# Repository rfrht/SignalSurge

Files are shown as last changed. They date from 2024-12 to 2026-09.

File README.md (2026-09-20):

# SignalSurge
This is an open source (check licensing [here](https://github.com/rfrht/SignalSurge/blob/main/LICENSE)) Bandpass filter for VHF and UHF amateur radio bands, with a selectable LNA and a sequencer. Designed using Eagle CAD 9.

# Why?
I live in a highly RF-polluted metropolitan area. One of these days, only FFS I have added a FM bandstop filter and I found that, contrary to my belief, my reception was **way better**! That means:

1. The front-end radio filtering is less than great (even being an expensive FT-991A)
2. Strong out of amateur band signals (and there's **plenty** of them) will desensitize your radio
3. By filtering out unwanted signals, you give more **dynamic range** to your radio, improving your reception.
4. [See for yourself here](https://www.reddit.com/r/amateurradio/comments/1gxahma/noticeable_improvement_in_ft991a_2m_rx_when_using/).

That said, the objective of this project is to remove as much as possible signals outside 2m and 70 cm bands (like: FM broadcasts, air band, commercial VHF & UHF, and everything else inbetween), ensuring that the precious front-end gain on the radio's built-in amplifier focuses on amateur band signals as much as possible.

I could buy a [300 EUR filter](https://antennas-amplifiers.com/double-2x200w-bandpass-filter-144-148mhz-430-450mhz/), but... man, that's expensive. So why not spend €3,000 worth of my own man-hours and parts to build one?

# Features
* Two **selectable** amateur band (2m and 70 cm) [bandpass filter](https://github.com/rfrht/SignalSurge/blob/main/rf-performance.md) weeds out signals, ensuring that the transceiver front-end focus its gain figures on inband signals only. That can be automated by making use of the Band Data (`TUN/LIN` port, pins `4` or `5`). Requires menu config 141 (`TUNER SELECT`) to be set as `LAMP`.
* **High performance** and selectable [low noise 15 dB amplifier](https://github.com/rfrht/SignalSurge/blob/main/rf-performance.md#amplifier-performance) (Infineon BFP460) after the bandpass filter, adding some oomph to weak signals
* Nearly **-70 dB of rejection** against the FM broadcast band
* The amplifier is **shut down when the radio is transmitting** by powering off its 5V rail (by cutting the regulator "Enable" line) to prevent any artifacts/ringing and damage. 
* Specialty RF relay allowing 50W in VHF/UHF frequencies to flow to the antenna with **low loss**, while keeping **[unparalleled isolation](https://www.reddit.com/r/rfelectronics/comments/1h5mthn/comment/m0de8n7/) (north of 60 dB)** to the downstream components
* Relay **default state (NC) is to bypass** radio directly to antenna, allowing the board to be safely powered off
* [TX Inhibit](https://github.com/rfrht/FT-991A/blob/master/understanding-ft-991a-tx-inhibit.md) logic outputs +13.8V to the FT-991A's TUN/LIN port whenever the delicate BPF/LNA chain is active, **preventing accidental** 50W transmissions into the low-power solid-state switches and filter chain
* **Static bleeding and small [surge protection](https://www.digikey.com/en/products/detail/eaton-electronics-division/0603ESDA2-TR2/3681416)** when switched to BPF/AMP
* [Via-Stitched Grounded Coplanar Waveguides (GCPW)](https://resources.altium.com/p/pros-and-cons-of-different-high-frequency-transmission-line-types) ensures strictly controlled 50-ohm impedance and suppresses parasitic radiative modes. Real-world proof: the board effortlessly handles **50 Watts** (+47 dBm) of 70cm RF on an open bench **without radiating** into the room or causing the dreaded "speaker buzz" in nearby unshielded subwoofers.
* A **[detachable miniature](https://github.com/rfrht/SignalSurge/blob/main/others/miniature-filter-board.jpg)** VHF BPF filter that [fits perfectly](https://github.com/rfrht/SignalSurge/blob/main/others/miniature-filter.jpg) in [RTL-SDR](https://www.rtl-sdr.com/rtl-sdr-com-broadcast-fm-band-stop-filter-88-108-mhz-reject-now-for-sale/) [FM bandstop cases](https://github.com/rfrht/SignalSurge/blob/main/others/encased-miniature-filter.jpg). **NOTE:** This filter DOES NOT withstand TX power; it will **fry** the inductor! Do not transmit on it.

## Library
Eagle custom component library [here](https://github.com/rfrht/FT991A-PAT/blob/master/Schematic/aarf.lbr). Ensure to **also** fetch the latest library version (and update in your Eagle) when checking out new code.

Bill of Materials (CSV format, DigiKey format) [here](https://github.com/rfrht/SignalSurge/blob/main/others/SS.csv). Notice that there's a full RF Inductor and Capacitor kit specified in the BOM - and that is **costly**. If you have the suitable RF L/C components, fine! Otherwise (like me), buy a proper one.

# Schematic: 
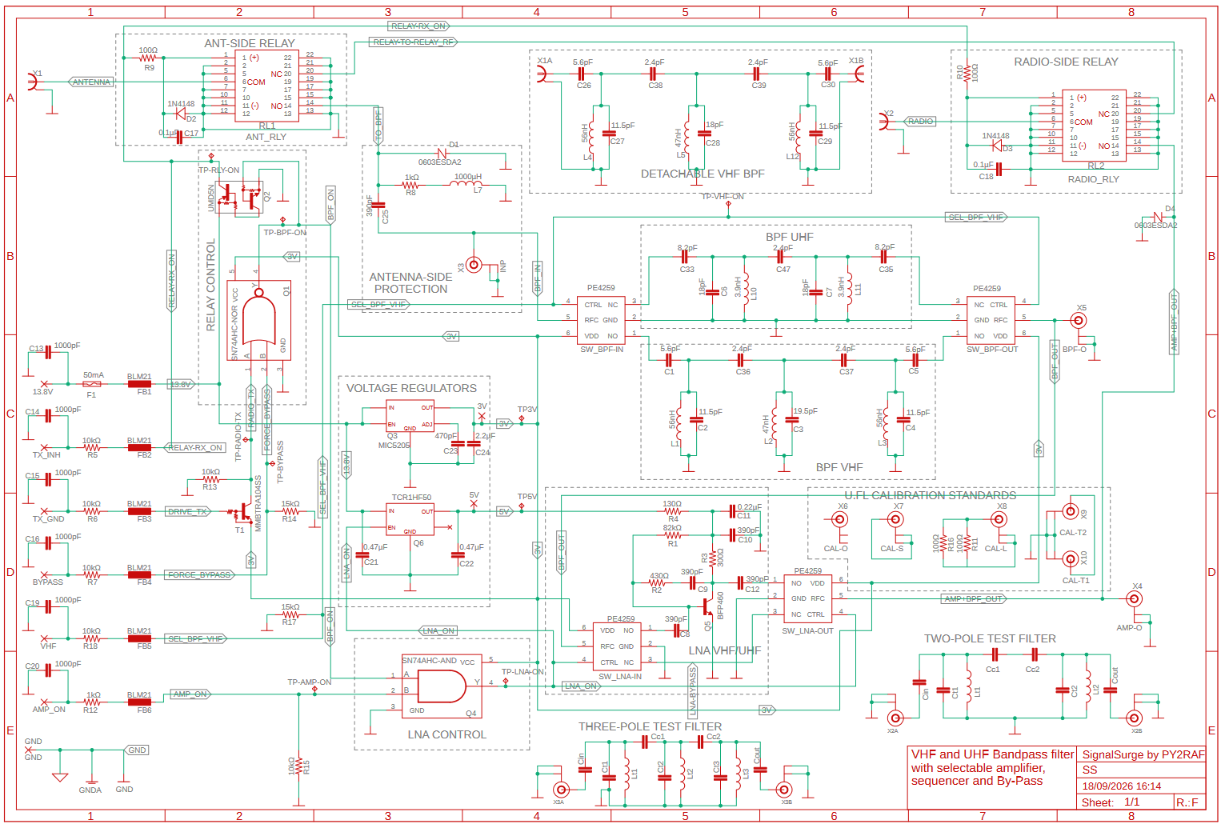
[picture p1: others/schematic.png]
Schematic SignalSurge


# Board layout
[Rev. E1 populated board](https://github.com/rfrht/SignalSurge/blob/main/others/ss-board-finished.jpg)

# BPF & Amplifier performance
Check the [test results](https://github.com/rfrht/SignalSurge/blob/main/rf-performance.md) page.

# Relay Logic
Check the [relay logic](https://github.com/rfrht/SignalSurge/blob/main/others/relay-logic.md) page.

# Test, troubleshooting steps & Specs
Yes - I have provided a [step by step testing and troubleshooting](https://github.com/rfrht/SignalSurge/blob/main/others/testing.md) guide!

# KNOWN ISSUES
**Ensure** to check the [Issues backlog](https://github.com/rfrht/SignalSurge/issues)

# JOURNEY
* Sep 18 - Updating the test figures. Successfully used the [TX INH](https://github.com/rfrht/FT-991A/blob/master/understanding-ft-991a-tx-inhibit.md) functionality at the radio. Released Rev. F.
* Sep 14 - Starting Rev. F. Changed "Bypass" and "VHF/UHF" selectors to input 5V in order to be able to use the [BCD decoders from FT-991 band data](https://hf5l.pl/en/1472-2/) at the TUN/LIN port. Added u.FL calibration pads.
* Sep 12 - Assembled board Rev. E1. Documented RF performance.
* Jun 06 - Improved UHF filter, making it narrower (50 to 30 MHz wide) and less lossy. Added another component in UHF schematic/board in order to allow for a fine tune capacitance of the coupling stage.
* May 28 - Fixed a gross error where a via shorted the VHF BPF final coupling stage. Removed ground pad on inductors at the detachable VHF BPF. Improved the radio signal trace at the first RF relay input. Updated component values for the 3-pole VHF filter (*in vivo* performed differently than the *in vitro*)
* May 04 - Replaced 3V regulator (was above its maximum rated) with a MIC5205. Removed a pulldown resistor in VHF line. Unified pulldowns on 10k and pulled lines limiters at 1k. Removed a pulldown between the NOR and AND logic ICs
* May 03 - Vibe-coded a new UHF filter with Gemini. Refactored the board, the filters, waveguides, soldermask, signal path
* May 01 - Starting Revision E. Vibe-coded a new VHF filter with Gemini
* Mar 19 - Removed two unneeded RF switches at the front-end: extra cost, complexity and insertion loss - unnecessarily, as the RF stage is handsomely isolated - and powered off during high power operations.
* Feb 28 - Found the need of a pulldown resistor in the VHF switch line. Refactored the CPW between the relays, hoping this tackle the high VSWR in 70 cm band.
* Feb 27 - Finished the board soldering, added the relays and SMA connectors. First back-to-back gain tests. First VSWR tests.
* Feb 22 - Pushing Rev. D
* Feb 20 - Finished BPF and LNA tests
* Feb/2026 - Got the Rev. C boards
* Dec 30 - Refactored the coplanar waveguides (CPW)
* Dec 29 - Changed layout of BPF section, separating inductors at 90° - Gemini said it's a good practice
* Dec 28 - Reviewed the board layout, added descriptions to signal lines, refactored the detachable VHF BPF, fixed a pernicious board cut failure to render (it was my fault)
* Dec 25 - [Used Gemini to design a VHF BPF](https://github.com/rfrht/SignalSurge/blob/main/others/gemini-prompt.md) - which yielded [pretty good results](https://github.com/rfrht/SignalSurge/blob/main/rf-performance.md), *tips hat to AI*
* Dec 25 - Starting Rev. C. 
* Aug 31 - Tested the VHF BPF and it was way out of line. Shelved the project for a while.
* Aug 31 - Added pulldown lines in comparators, routing change on the back of the board, unified logic ICs into SC70-5 footprint, updated BOM to add new pulldown resistors, better footprint for BFP460 and NCP553, fixed wrong 0.22µf part (it was 0.022µf) in BOM
* Jul 09 - Added a detachable board (taking advantage of the spare board real estate) that fits a RTL-SDR Bandpass filter. Minor signal and label revisions, routing, better labeling for signal I/O by adding expected voltages, improved semiotics. Tentatively final.
* May 18 - Fixed the Rev. A defects, check the [changelog here](https://github.com/rfrht/SignalSurge/commit/eed25a111f6a104a3589aa6e2ec3a4192e9d5c3d)
* Mar 17 - Tested relay logic (it is sound!), voltage regulators. And also fried the first board by shorting the 13.8V line on the 3V line **before** the fuse.
* Mar 16 - Tweaked the filter to bring the peak 2m BPF performance to the center of the band (146 MHz). Done in trial and error.
* Mar 11 - The boards arrived and assembled the Rev. A board - the BPF works! A bit out of frequency, but it works. More testing and component tweaking in the make.
* Feb 19 - All parts inventoried and accounted for. Placed the board order
* Feb 07 - Bought the needed parts!
* Jan/2025 - Reached the "minimally lovable project" stage.

# CHANGELOG
* Rev. F: Improved UHF BPF. Changed "Bypass" and "VHF/UHF" input selectors from 3V to 5V via resisitive divisors. Added u.FL calibration pads.
* Rev. E: Complete rewrite of VHF BPF to a proper 3-pole, improved UHF filter performance significantly, implemented a proper 50 ohm GCPW setup, re-added soldermask into the signal path, added a two-pole and three-pole test pad at the back of the board. Fixed u.FL connectors lacking connection to ground in one side. Added keep-out zones for inductors. Replaced the 3V regulator. Separated the top ground plane on north/south: The north (RF) section doesn't have any thermal relief in GND pads. The south (ancillary) section contains thermal relief GND pads.
* Rev. D: Changed 74XX pulldown lines to 100k, fixed UMD5N pin order, small tweak in UHF filter (caps changed to 20 pF). Added pulldown to VHF switch line. Rounded bypass CPW layout. Extra silkscreen. Removed exposed pads for shielding (might capacitive couple with the components). Removed unnecessary RF switches at the front-end.
* Rev. C: New VHF BPF topology, added a test UHF BPF on the back of the board, improved the LNA board layout, fixed capacitor pads (was too small)
* Rev. B: Added test points, changed connectors to SMA (big signal) and U.FL (small signal and test)
* Rev. A: Initial release

# ACKNOWLEDGEMENTS
I'd like to thank the following contributors:
* The fine [r/rfelectronics](https://www.reddit.com/r/rfelectronics/) community for helping me [square out a RX mute/isolation](https://www.reddit.com/r/rfelectronics/comments/1h0pffq/help_me_reuse_this_circuit/) (tip: it was right under my nose) issue and [how to select the large signal switch](https://www.reddit.com/r/rfelectronics/comments/1h5mthn/help_select_high_power_50w_uhf_switch/) and [a critical review of the bandpass filters](https://www.reddit.com/r/rfelectronics/comments/1hk1mgi/sanity_check_in_vhf_uhf_bpf_filters/)
* The [r/AskElectronics](https://www.reddit.com/r/AskElectronics/) community for [the sanity checking on using a PNP transistor to switch a ground signal](https://www.reddit.com/r/AskElectronics/comments/1hanp3u/will_this_switch_when_tx_gnd_is_grounded/).
* The mighty and fine [**Gordon Hudson** (AD5GG)](https://www.qrz.com/db/AD5GG) for: guiding me on component layouts, deciding for a proper impedance control, his primer on CPWs (coplanar waveguides) and assorted awesomeness.

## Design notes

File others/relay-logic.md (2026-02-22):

# BPF and Relay control
This is the documentation of the relay and RF switches state coordination.

## Truth table (NOR)
| RADIO_TX | FORCE_BYPASS | Logic Result | Behavior |
:---|---|---|---:
| 0 | 0 | 1 | VIA BPF |
| 0 | 1 | 0 | BYPASS |
| 1 | 0 | 0 | BYPASS |
| 1 | 1 | 0 | BYPASS |

## RX/Via BPF states:
| Circuit | Connected to  | Power |
:---------|---------------|--------:
| Relays  | NO | + |
| Isolation | NO | + |

## TX/Bypass states:
| Circuit | Connected to  | Power |
:---------|---------------|--------:
| Relays  | NC | - |
| Isolation | NC | - |

# LNA Control
## Truth Table (AND)
| BPF_ON | LNA_ON | Logic Result | Behavior |
:---|---|---|---:
| 0 | 0 | 0 | OFF |
| 0 | 1 | 0 | OFF |
| 1 | 0 | 0 | OFF |
| 1 | 1 | 1 | ON |

## LNA On
| Circuit | Connected to  | Power |
:---------|---------------|--------:
| V.REG.  | EN | + |
| LNA SW  | NO | + |

## LNA Off
| Circuit | Connected to  | Power |
:---------|---------------|--------:
| V.REG.  | EN | - |
| LNA SW  | NC | - |

The VHF/UHF selector is NORMALLY CONNECTED (NC) to the UHF BPF. By providing a 3V input to the VHF header, the BPF RF switches transition to NO (normally open) state and diverts the signal to the VHF chain.

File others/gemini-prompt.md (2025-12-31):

# BPF Gemini vibe designing
## Prompt
I want to create a radio frequency band pass filter centered at 146 MHz with bandwidth 4 MHz wide. What is the best topology for this filter, considering L, T or Pi networks? I don’t have any special need for delay groups. 

## Answer
For a filter centered at **146 MHz** with a narrow **4 MHz bandwidth** (approx. 2.7% fractional bandwidth), the standard "L," "T," or "Pi" networks used for broad low-pass or high-pass filtering are not suitable on their own.

The best topology for this application is the **Top-Coupled Capacitive Bandpass Filter** (often called a **Nodal** or **Tubular** filter).

While this topology visually resembles a chain of Pi-networks, it functions differently. It consists of parallel LC resonant tanks connected (coupled) by small series capacitors.

### Why this is the Best Topology
1. **Realizable Component Values:** If you tried to design this as a standard "Pi" bandpass (converting a Low Pass prototype directly), the series arm would require an inductor and capacitor in series that are impractical to realize at 146 MHz for such a narrow bandwidth. The top-coupled topology keeps all inductors as "shunt" elements (connected to ground), which is mechanically stable and easy to tune.
2. **High Q Capability:** A 4 MHz bandwidth at 146 MHz requires a Loaded Q of approximately 36.5. This topology allows you to use high-Q air-core inductors to minimize insertion loss.
3. **Tunability:** Since the inductors are grounded, you can easily use air-wound coils and stretch/compress them to tune the center frequency without desoldering components.
---

### Recommended Topology Structure
The filter is constructed as a cascade of **Resonant Tanks** coupled by **Series Capacitors**.

**Structure (3-Pole Example):**
`[Input Match] — [Tank 1] — [C12] — [Tank 2] — [C23] — [Tank 3] — [Output Match]`

* **Tanks (1, 2, 3):** Each "Tank" is an Inductor and Capacitor in parallel, connected between the signal line and ground.
* **Coupling Caps (C12, C23):** Small capacitors in series between the tops of the tanks. These control the bandwidth.
* **Input/Output Matching:** Since the impedance of the tanks is very high at resonance, you cannot connect a  cable directly to the top. You must "tap" down.
* *Option A (Inductive Tap):* Connect the input coax to a tap point roughly 1-2 turns up from the grounded end of the coil.
* *Option B (Capacitive Divider):* Split the resonant capacitor into two series capacitors. Connect the input between them.

### Design Guidelines (146 MHz)
Since you do not need flat group delay, a **Chebyshev** response (0.1 dB or 0.5 dB ripple) is recommended. It gives you sharper "skirts" (better rejection of signals at 140 MHz or 152 MHz) compared to a Butterworth filter.

#### 1. Component Selection
* **Inductors:**
* Use air-core coils. roughly **50 nH to 80 nH**.
* *Construction:* 4 to 6 turns of AWG 18-20 wire, roughly 6-8mm diameter.
* *Why:* High Q is essential. Do not use small SMD inductors; their Q is too low, and your filter will have high signal loss (Insertion Loss).

* **Resonant Capacitors:**
* Use High-Q RF capacitors (C0G/NP0 ceramic or silver mica).
* Value will likely be in the **15 pF to 30 pF** range.
* Include a trimmer capacitor (e.g., 2-10 pF) in parallel with each tank for fine-tuning.

* **Coupling Capacitors:**
* These will be very small, likely **1 pF to 4 pF**.
* Use high-precision (±0.1 pF) C0G capacitors.

#### 2. Layout & Shielding
* **Shielding is Critical:** Because the coils are air-core, they act like antennas. If Tank 1 "sees" Tank 3 magnetically, the filter will not work (the stop-band rejection will be ruined).
* **Solution:** Place each LC tank in its own small shielded compartment (using double-sided PCB material as walls), or orient the coils at 90-degree angles to each other to minimize magnetic coupling.

### Summary of Specifications

| Parameter | Value | Note |
| --- | --- | --- |
| **Center Freq** | 146 MHz | 2m Amateur Band |
| **Bandwidth** | 4 MHz |  |
| **Topology** | Top-Coupled Capacitive | Best for narrow band VHF |
| **Filter Shape** | Chebyshev | Best selectivity for component count |
| **Coupling** | Series Capacitors | Controls the 4 MHz width |
| **Matching** | Capacitive Divider | Matches 50$\Omega$ to High-Z tank |

**Would you like me to calculate the specific capacitor and inductor values for a 3-pole Chebyshev design (standard for this application)?**

## Prompt
Yes, please

## Answer
Here are the specific component values and design details for a **3-Pole Top-Coupled Bandpass Filter** centered at **146 MHz** with a **4 MHz bandwidth** (Chebyshev response, 0.1 dB ripple).

### 1. The Circuit Topology
The filter consists of three parallel LC tanks connected to ground, coupled together by small series capacitors at the top. The input and output are matched using capacitive dividers.

**Visual Representation:**

```text
Input (50Ω)
   |
  [Cm]         [Ck]         [Ck]         [Cm]
   |-----|------|-----|------|-----|------|----- Output (50Ω)
   |     |      |     |      |     |      |
 [C1]   [L1]  [C2]   [L2]  [C3]   [L3]   [RL]
   |     |      |     |      |     |      |
  GND   GND    GND   GND    GND   GND    GND

```

* **L1, L2, L3:** Air-core Inductors (shunted to ground).
* **C1, C2, C3:** Main resonant capacitors (shunted to ground).
* **Ck:** Coupling capacitors (series).
* **Cm:** Matching capacitors (series input/output).

---

### 2. Component Values

These values are calculated for a **60 nH** inductor base, which is a convenient size for 2-meter band filters (easy to wind and high Q).

| Component | Value | Practical Implementation |
| --- | --- | --- |
| **Inductors (L1, L2, L3)** | **60 nH** | **Air Core:** ~4 turns of AWG 18 wire, 6mm (0.25") diameter, spaced to length of ~8mm.<br>*(Adjust spacing to tune)*. |
| **Coupling Caps (Ck)** | **0.6 pF** | **"Gimmick" Capacitor:** Twist 2 insulated wires together for ~10mm. Trim length to tune bandwidth. Alternatively, use **0.5 pF** high-Q ceramic. |
| **Input/Output Match (Cm)** | **3.3 pF** | High-Q Ceramic (C0G/NP0). Use a standard **3.3 pF**. |
| **End Tank Caps (C1, C3)** | **16 pF** | Use a **10 pF fixed** + **10 pF trimmer** (Green). <br><br>*(Reduced value accounts for loading from Cm).* |
| **Middle Tank Cap (C2)** | **19 pF** | Use a **10 pF fixed** + **10 pF trimmer** (Green). |

### 3. Critical Construction Details

#### Why the values are "low"
You will notice the Coupling Capacitor is extremely small (**0.6 pF**). This is normal for a narrow bandwidth (4 MHz) at this frequency.

* If  is too **large**, the bandwidth will become **too wide** (e.g., 10-20 MHz).
* If  is too **small**, the bandwidth will be **too narrow** and insertion loss will rise.

#### The "Gimmick" Capacitor
Because 0.6 pF is hard to find with tight tolerance, builders usually create a "Gimmick" capacitor:

1. Take two 2-inch pieces of insulated wire (enamel wire or plastic coated hookup wire).
2. Twist them tightly together.
3. Solder one end of wire A to Tank 1, and one end of wire B to Tank 2. (Leave the other ends floating).
4. **Tuning:** Cut the twisted wire shorter with clippers. As you cut it shorter, capacitance decreases, and bandwidth narrows.

#### Tuning Procedure
1. **Center Frequency:** Adjust the **L coils** (stretch/compress) or the **Trimmer Capacitors** on C1, C2, and C3 to peak the signal at 146 MHz.
2. **Bandwidth:** If the filter is too narrow, increase  (twist more wire). If it is too wide, decrease  (cut the wire).

### 4. Expected Performance
* **Insertion Loss:** < 2.5 dB (Dependent on the Q of your hand-wound coils).
* **Return Loss:** > 15 dB (Good match to 50 Ohms).
* **Rejection:** Should provide excellent rejection of FM broadcast (98-108 MHz) and pager/commercial signals (150-160 MHz).

Would you like me to explain how to physically shield these coils to prevent magnetic coupling from ruining the filter response?

## Prompt
Yes, please

## Answer
For a filter with air-core coils at 146 MHz, shielding is not just a precaution—it is a requirement. Without it, the magnetic fields from Coil 1 will induce current directly into Coil 3 (skipping the middle stage), which destroys your stop-band rejection.

Here is how to physically construct the shielding.

### 1. The "Three-Chamber" Box Method (Recommended)
The standard professional approach is to build a "coffin" or box divided into three separate compartments. This isolates each LC tank completely.

* **Materials:** Double-sided copper-clad board (FR4 PCB material) or thin brass/tin sheet.
* **Construction:**
1. Cut a rectangular base plate (ground plane).
2. Solder vertical walls to create a box with 3 distinct square rooms (e.g., 20mm x 20mm each).
3. **The Divider Walls:** The walls separating the rooms act as the shields.

* **The Connection Hole:** Drill a small hole (approx 3mm) in the divider walls. The coupling capacitor (or the twisted wire "gimmick") passes through this hole to connect the top of Tank 1 to the top of Tank 2.
* *Note:* Keep the hole small. A large hole allows magnetic waves to leak through.

### 2. Orthogonal Coil Orientation (NOTE: Picked this method)
If you cannot build a full metal enclosure, you must orient the coils so their magnetic fields do not overlap. This is called "Orthogonal Placement."

* **Coil 1:** Mount horizontally (Left-to-Right axis).
* **Coil 2:** Mount vertically (Up-and-Down axis).
* **Coil 3:** Mount horizontally (Front-to-Back axis).

*Why this works:* The magnetic field lines of Coil 1 will hit Coil 2 at a 90-degree angle, inducing almost zero current.
*Limitation:* This is harder to do with 3 coils than with 2. The Chamber Method (#1) is superior for 3-pole filters.

### 3. The "Distance Rule" (Eddy Currents)
While shielding prevents coupling, placing a metal shield too close to a coil will kill its "Q" (efficiency). The magnetic field induces "eddy currents" in the shield wall, which turn your RF signal into heat.

* **Rule of Thumb:** Keep the shield walls at least **one coil diameter** away from the coil itself.
* *Example:* If your 60 nH coil is 6mm wide, the metal walls should be at least 6mm away from the copper wire on all sides.
* *Result:* Each compartment should be roughly 20mm x 20mm wide/tall.

### Summary Checklist for Construction
1. **Base:** Solid copper ground plane (un-etched PCB).
2. **Mounting:** Solder the bottom leg of the inductor and the bottom leg of the trimmer capacitor directly to the floor (ground plane) for minimal lead length.
3. **Isolation:** Solder vertical walls between Stage 1, 2, and 3.
4. **Coupling:** Pass the small coupling capacitor through a small hole in the wall.

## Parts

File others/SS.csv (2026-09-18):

Qty | Value | Parts | DigiKey
1 | 2.2µF | C24 | 490-GRM21BR71E225KE11KCT-ND
2 | 0.47µF | C21 C22 | 1276-6480-1-ND
1 | 0.22µF | C11 | 1276-6478-1-ND
2 | 0.1µF | C17 C18 | 1276-6840-1-ND
6 | 1000pF | C13 C14 C15 C16 C19 C20 | 732-8050-1-ND
1 | 470pF | C23 | 732-7837-1-ND
5 | 390pF | C8 C9 C10 C12 C25 | 399-C0805C391J4HACTUCT-ND
3 | 2.4pF | C34 C36 C37 | 311-3853-1-ND
1 | 1000µH | L7 | 587-2041-1-ND
6 | BLM21 | FB1 FB2 FB3 FB4 FB5 FB6 | 490-1041-1-ND
1 | 82kΩ | R1 | 118-CR1206-FX-8202ELFCT-ND
7 | 10kΩ | R5 R6 R7 R13 R15 R18 R19 | CR1206-FX-1002ELFCT-ND
2 | 15kΩ | R14 R17 | CR1206-FX-1502ELFCT-ND
2 | 1kΩ | R8 R12 | CR1206-FX-1001ELFCT-ND
1 | 430Ω | R2 | 118-CR1206-FX-4300ELFCT-ND
1 | 300Ω | R3 | CR1206-FX-3000ELFTR-ND
1 | 130Ω | R4 | 118-CR1206-FX-1300ELFCT-ND
2 | 100Ω | R9 R10 | CR1206-FX-1000ELFCT-ND
2 | 0603ESDA2 | D1 D4 | 283-0603ESDA2-TR2CT-ND
2 | 1N4148 | D2 D3 | 1801-1N4148WSR9GCT-ND
1 | MMBTRA104SS | T1 | 4878-MMBTRA104SSCT-ND
1 | 50mA | F1 | 283-3132-1-ND
2 | ANT_RLY | RL1 RL2 | PB2069CT-ND
2 | SMA-PCB | X1 X2 | 2072-RFPC-SMA28-F-ND
2 | SMA-EDGE | X1A X1B | 2057-RF2-145A-T-17-50-G-HDW-ND
3 | U.FL | X3 X4 X5 | A144746CT-ND
1 | SN74AHC-AND | Q4 | 296-8743-1-ND
1 | SN74AHC-NOR | Q1 | 296-11598-1-ND
1 | UMD5N | Q2 | UMD5NCT-ND
1 | MIC5205 | Q3 | 576-1258-1-ND
1 | BFP460 | Q5 | BFP460H6327XTSA1CT-ND
1 | TCR1HF50 | Q6 | TCR1HF50B-LM-CT
4 | PE4259 | Q7 Q8 Q9 Q10 | 1046-1011-1-ND
1 | Cap Kit | RF Capacitors | 712-1370-ND
1 | Ind Kit | RF Inductors | 712-1545-ND

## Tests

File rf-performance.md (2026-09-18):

# RF Performance

## VHF BPF
The VHF filter is a 3-Pole Top-Coupled Chebyshev Bandpass Filter. This is the first stab, simulated filter performance, modeled by LTSpice:

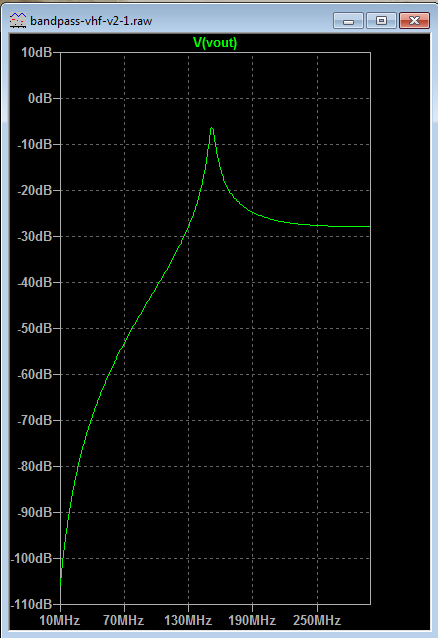
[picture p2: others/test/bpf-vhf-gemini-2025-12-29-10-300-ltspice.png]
Theoretical VHF filter


This is how the filter on 10 MHz - 300 MHZ VNA sweep of the VHF BPF - this was tapped right at the BPF stage, without any extra other insertion loss (switches, amps, etc). It provided a very decent isolation for the lower bands, FM broadcast and other general out-of-band signals.

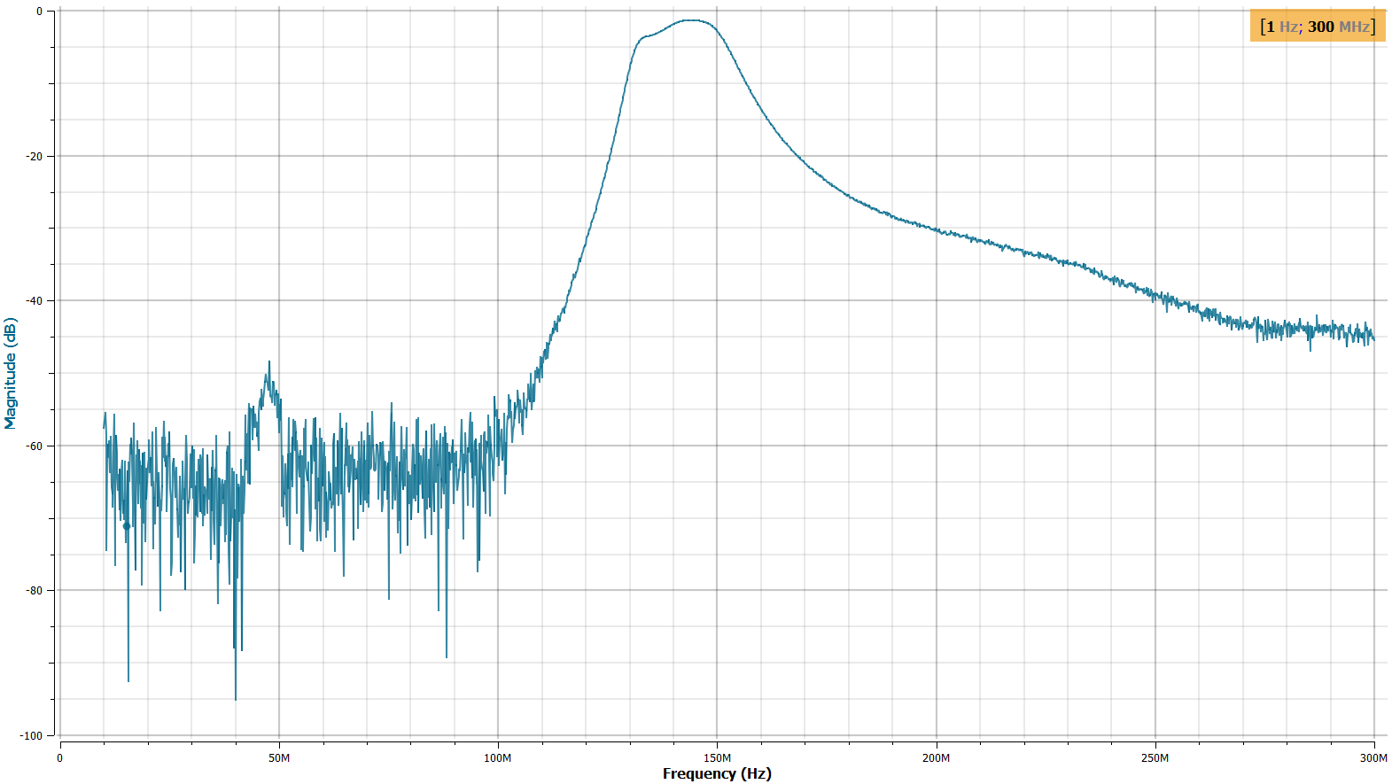
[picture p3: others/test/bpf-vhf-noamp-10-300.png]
Out of box VHF BPF


This is the VSWR and insertion loss sweep of the 2m amateur band - tested with a fully assembled board, SMA-to-SMA:

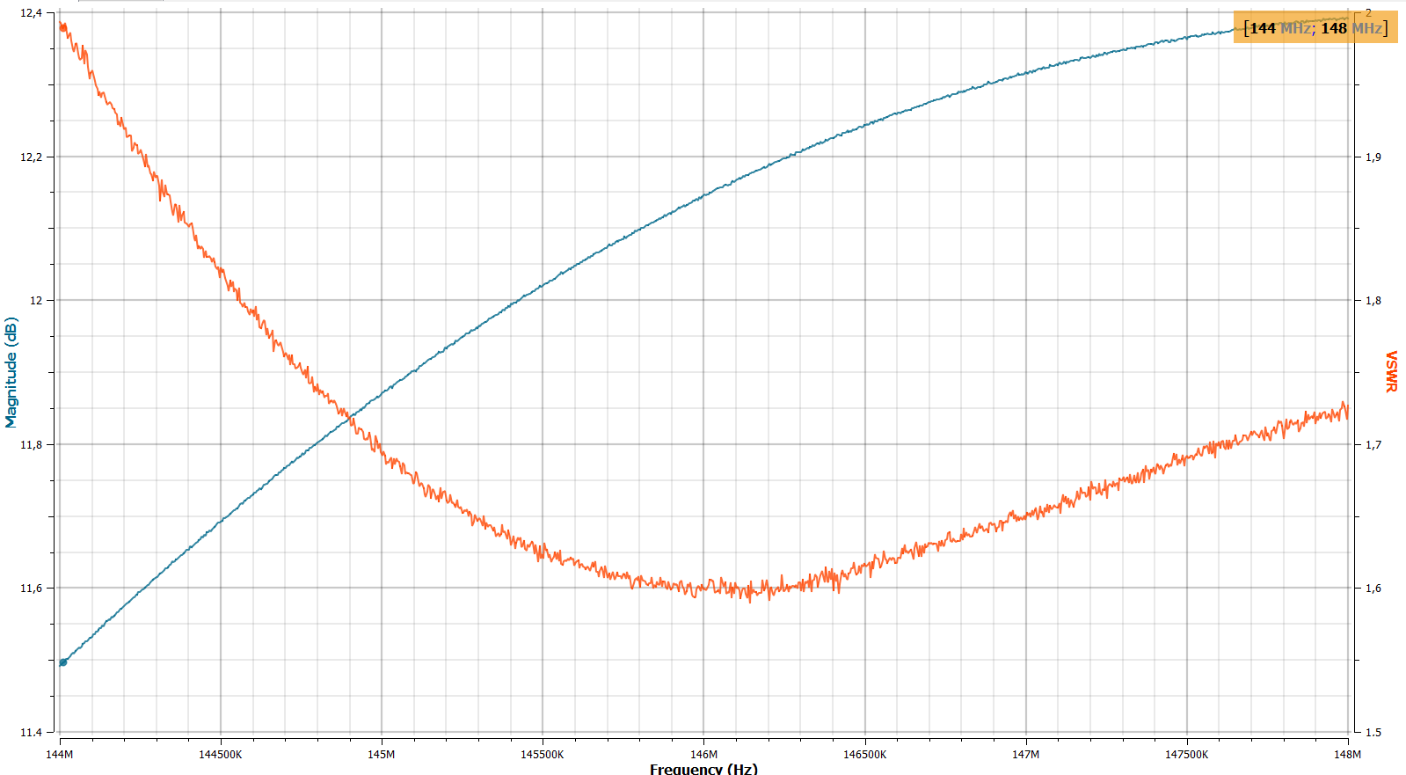
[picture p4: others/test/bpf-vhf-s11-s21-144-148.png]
2m VHF BPF SWR performance


And this is a insertion loss sweep in the broadcast band, which is my key pain - Almost the entire band under -60 dB:

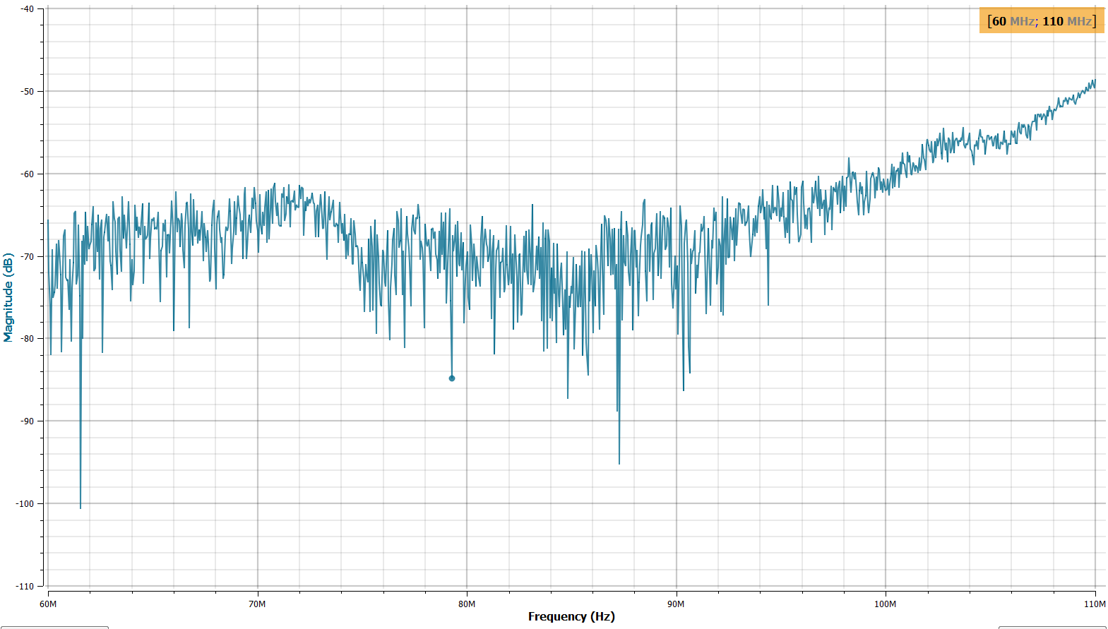
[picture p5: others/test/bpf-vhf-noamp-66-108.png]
FM Broadcast filter performance


## UHF BPF
The UHF filter is a 2-Pole Capacitively Coupled Parallel LC Resonator. Here is the theoretical projected filter performance:

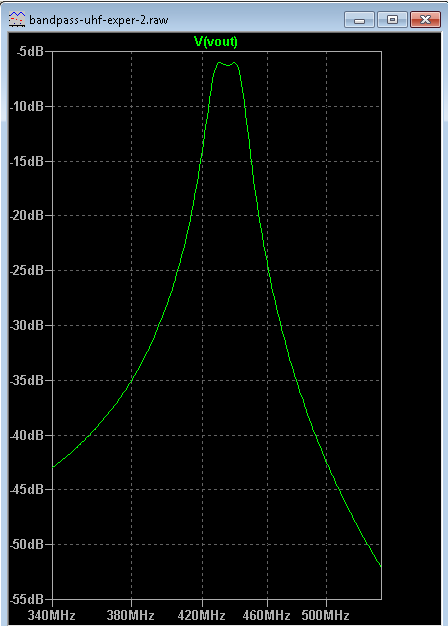
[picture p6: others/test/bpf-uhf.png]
Theoretical UHF BPF


And here is what the UHF filter delivered on a sweep from 10-600 MHz (testing it right at the BPF, without any extra insertion loss):

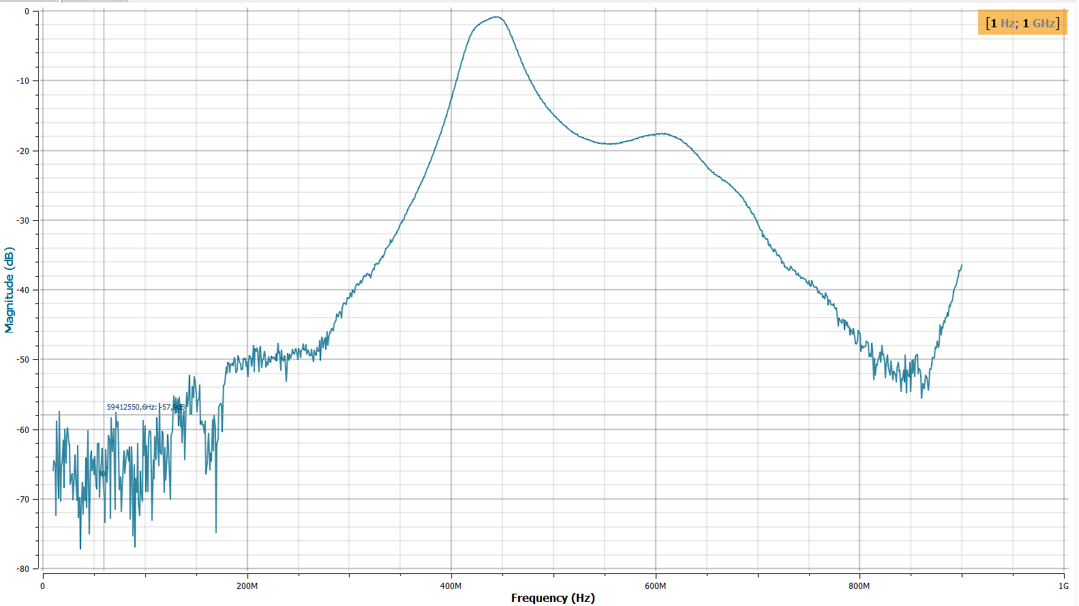
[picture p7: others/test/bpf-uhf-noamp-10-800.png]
UHF filter wide sweep


And this is how it is performing on 70 cm band, measuring insertion loss and VSWR in a fully assembled board, at the SMA connectors:

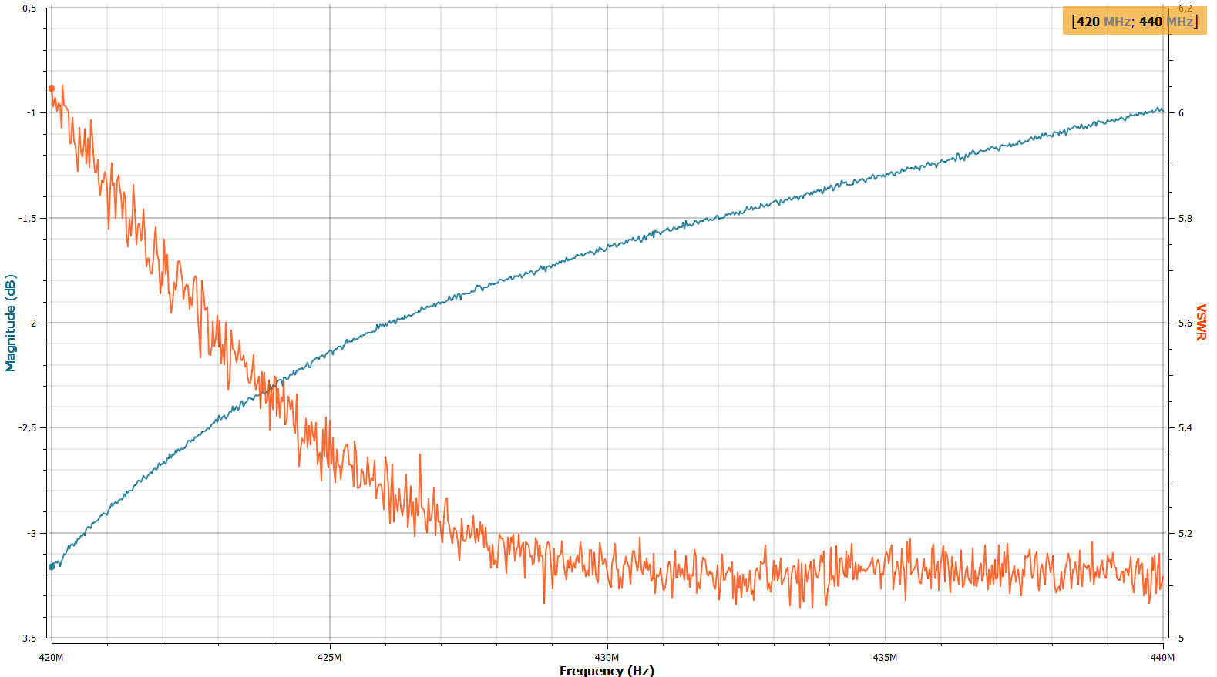
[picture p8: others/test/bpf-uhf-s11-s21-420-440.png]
70 cm band S11 and S21


## Amplifier performance
Here's the [BFP460](https://www.infineon.com/cms/en/product/rf/rf-transistor/low-noise-rf-transistors/bfp460/) gain figures, measuring solely the amplifier stage, without any extra insertion loss:

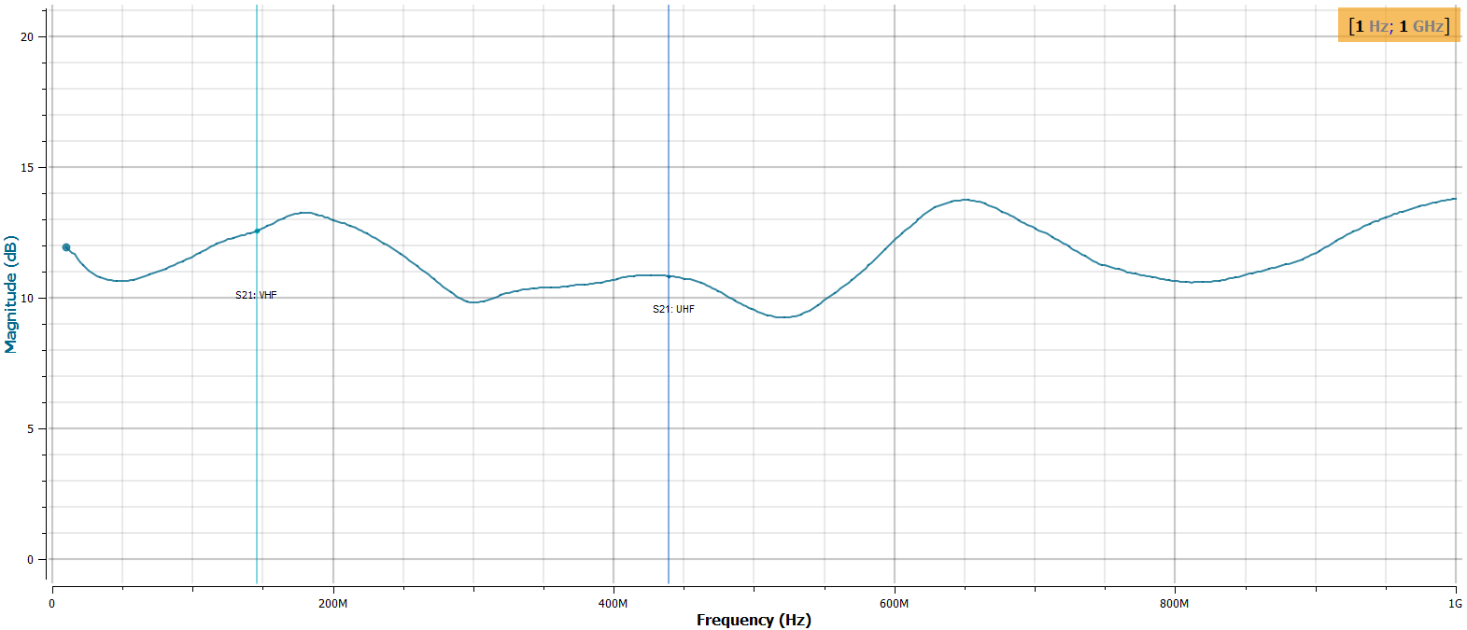
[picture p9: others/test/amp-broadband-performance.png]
Amplifier performance


The filter delivered approx. 10 dB of gain. 

Individual fully assembled board results, with signal travesrsing the BPF, connectors, switchetc etc, for VHF and UHF bands:

### VHF Gain
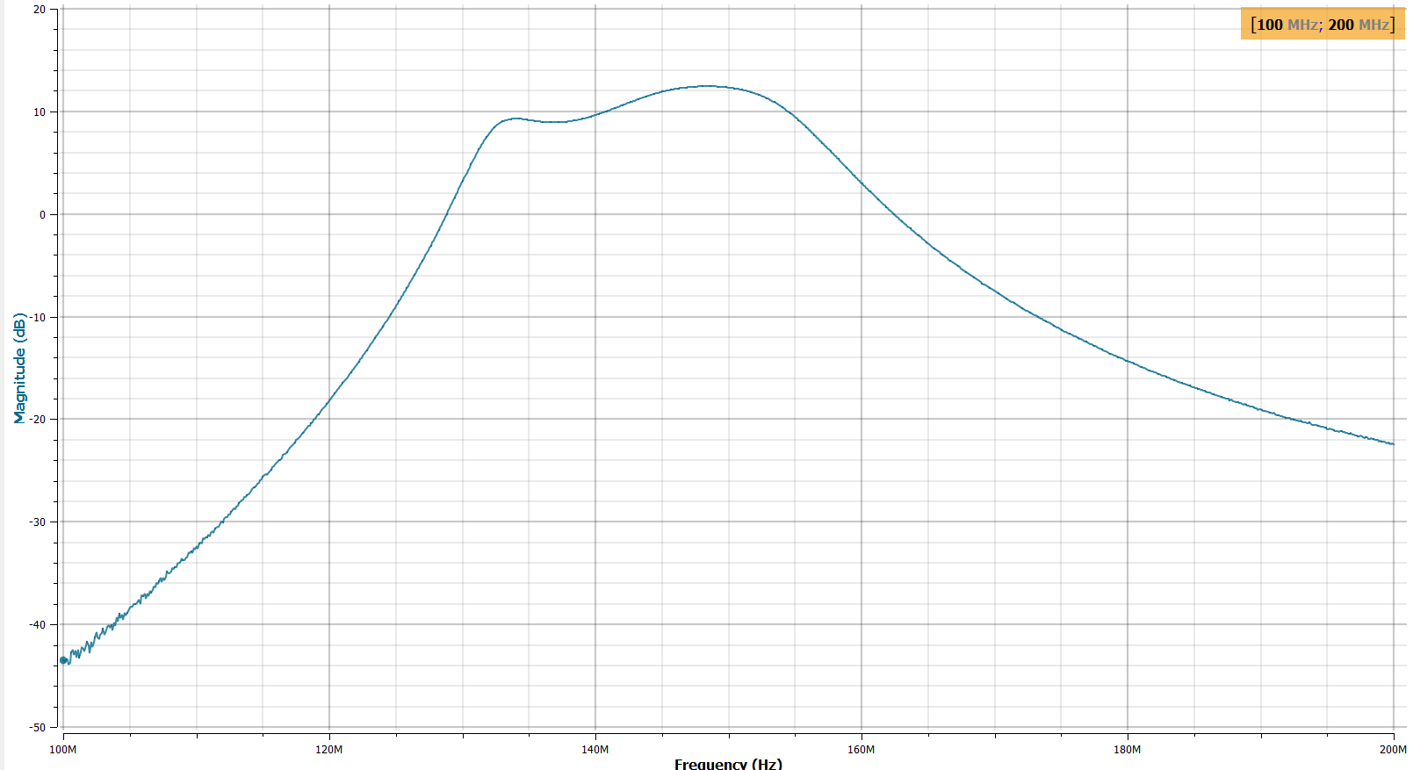
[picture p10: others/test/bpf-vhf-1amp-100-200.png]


### UHF Gain
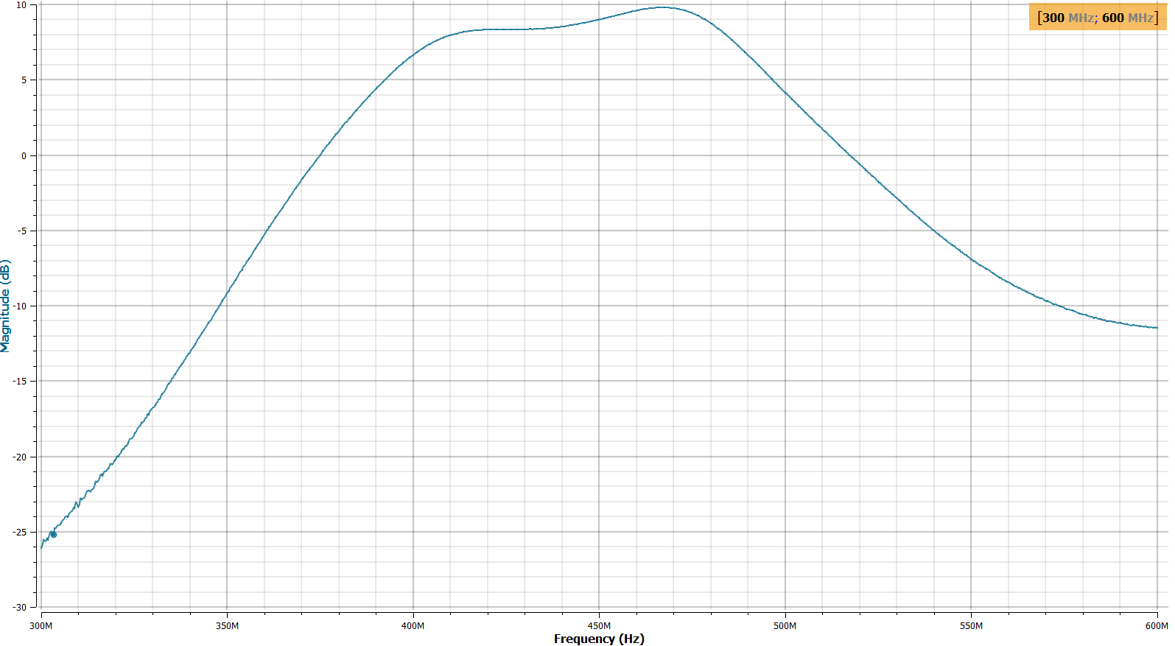
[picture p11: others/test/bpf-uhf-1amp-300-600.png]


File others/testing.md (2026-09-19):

# Device under Test
OOB VHF BPF

# Test sequence
Board picture - test sequence

* Start soldering the u.FL connectors `1` and `2`. Then the VHF/UHF BPF **discretes (caps & inductors) only**. Do not solder the RF switch just yet.

* Start testing with your VHF filter. Solder a bodge wire at the BPF RF switches footprints: They are `SW_BPF_IN` AND `SW_BPF_OUT` - requires good eyes and hands - to manually switch the VHF and UHF filters. Start bridging the u.FL with the **VHF BPF**.

* Now, measure the BPF performance. Inject signal from VNA Port 1 (Source) into the `INP` port (marked 1 in the image) and connect the VNA port 2 at the port `BPF-O`. Ensure that you have results similar to my [test results](https://github.com/rfrht/SignalSurge/blob/main/rf-performance.md).

* When all is fine, change your bodge wire to **switch it manually to UHF**. Redo the above test.

* When all is fine, remove the bodge wire from the `SW_BPF` RF switches. You might want to use solder wick to make your component footprint plain and remove excess solder. 

* Next up, solder the LOWER SECTION of the board: everything south of the BPF.

* Ensure that you have a solid 3V output at test point `TP3V`. Ensure that your fuse or any components (try with your fingers) aren't overheating.

* Feed 3V to the line `AMP_ON` header. Check the testpoint `TP_LNA_ON` have 3V and if your 5V regulator is throwing out a 5V output at the `TP5V` test point or the 5V terminal.

* Moving to the LNA. Solder a bodge wire at the `SW_LNA_IN` and `SW_LNA_OUT` pads, to bridge the U.FL lines `2` and `3` with the LNA stage.

* Inject signal from VNA Port 1 (Source) into the `BPF-O` connector, and measure the amplified output using VNA Port 2 (Receiver) at the `AMP-O` connector to correctly read S21 forward gain. Ensure that you are obtaining a good gain. If you mix the port order you will have a WRONG read! VNA port ordering is key here: Port 1 at `BPF-O`, Port 2 at `AMP-O`! Compare with my tests. And finally, ensure you soldered properly your BFP460. If you aren't getting any amplification, ensure that you didn't mix the VNA ports, have powered the LNA by powering the header `AMP_ON`.

* Remove the bodge wires. You may now solder the LNA RF switches.

* Redo the tests between the U.FL `BPF-O` and `AMP-O`, both ways: Amplifying and on bypass mode. Validate our outputs to establish a correctly working RF switch. NOTICE: they are FRAGILE! I damaged a number of them with a hot iron.

* Solder the BPF RF switches. Establish a working BPF switching between the u.FL connectors `INP` and `BPF-O`. Flip the switches by toggling the `VHF` line with 5V. Tip: You can tap 5V from the board header by turning on the amp by feeding 3V to the `AMP_ON` header.

* Solder the remaining parts at the UPPER SECTION of the board: First the SMD components, then the SMA port and finally the relays.

## Operational tests:

* When grounding `TX_GND`, all relays should be off. The same result is yielded when feeding 3V to the `BYPASS` port.

* When injecting 3V to `AMP_ON`, you turn on the amplifier. The presence of a `TX_GND` or `BYPASS` overrides and turns it off.

* The test point `TP5V` should be on only when `AMP_ON` has 3V at the header. Otherwise, it should be off.

* The line `TX_INH` sends 13.8V when the board is in RX mode (BPF/LNA engaged). When `TX_GND` or `BYPASS` are asserted, the board falls back to hardware bypass and the `TX_INH` line drops to 0V, safely allowing the radio to transmit.

* At the back of the board, there are the following tools: 2 pole filter, 3 pole filter and u.FL SOLT calibration pads.

If you have any further questions, get in touch or file an issue.

Yea, it'd be just easier if you bought that 300 EUR filter ;-)

## Power Consumption & Expected Current Draw
When troubleshooting the SignalSurge board, a standard multimeter placed in series with the main 13.8V power supply is your best diagnostic tool. The board operates at very low currents, making it easy to spot a blown component, a dead short, or a failed logic gate just by reading the milliamp (mA) draw.

The board is protected by a 50 mA PTC resettable fuse. If your board draws significantly more than the values below, immediately disconnect power and check for solder bridges/blobs/shorts or reversed diodes.

### Baseline Current Measurements
| Operational State | Expected Draw | Diagnostic Meaning |
| --- | --- | --- |
| **TX Mode / Manual Bypass** | **~0.5 mA** | **Quiescent State.** The Axicom HF3 relays are de-energized (hardware bypass) and the 5V regulator is either in shutdown or drawing minimal quiescent current. If this reads 0 mA, check your primary power connection. If it reads more than 1 mA, check the relay flyback diodes for leakage or shorts. |
| **RX Mode (BPF Only)** | **~18 mA** | **Relays Engaged.** The relay logic has successfully commanded the board to listen. The ~17.5 mA jump is the coil current required to physically hold the relays open, routing the RF signal through the PE4259 switch matrix and passive filters. |
| **RX Mode (BPF + LNA)** | **~24 mA** | **Full Active System.** The BFP460 amplifier is energized. The difference between this and the previous state is **~6 mA**. If the current jumps to > 30 mA here, the BFP460 is likely damaged or oscillating. |

### Being pedantic about power modes
* **Logic Override Test (`AMP_ON` + `TX_GND`):**
If `AMP_ON` is enabled and you trigger `TX_GND`, the current should instantly drop from **24 mA back to around 1 mA**.
* **VHF vs. UHF Logic Test:**
Toggling the FT-991A from 2-meters to 70cm (triggering BCD Pin 4) DOES NOT change the current draw. Switching between the PE4259 routing paths should result in a statistically zero difference in current (microamps). If you see a noticeable mA jump when switching bands, one of the RF switches is likely shorted to ground.
* **`TX_INH` Load Test:**
When connecting `TX_INH` to the radio, the `TX_INH` line sends +13.8V back to the radio and the total board current rises by around 1 mA when physically connected to the transceiver.

# Specifications
## Signal routing
### RX
* The signal enters the SMA Antenna connector
* Enters the first Axicom HF3 relay
* Finds a Eaton TVS PolySurge surge protector
* Static draining via a 1 kohm and 1000 µH inductor
* Encounters a 390 pF decoupling capacitor
* `INP` u.FL test port
* First RF switch, selects between VHF or UHF bandpass filter
* Enters the selected BPF
* Second RF switch, the exit section from the bandpass filter
* `BPF-O` test port
* Third RF switch, selects between the LNA section or bypass it, no amplification
* Fourth RF switch, LNA/bypass exit
* `AMP-O` test port
* Finds a Eaton TVS PolySurge surge protector
* Second Axicom HF3 relay
* Exit to radio port via SMA connector

All relays are protected by a 100 ohm current limiter resistor, a 1N4148 flywheel diode and a 0.1µF capacitor.

### TX
* The amplifier is de-energized by pulling off the `ENABLE` line from the 5V voltage regulator when detecting the `TX_GND` signal
* The signal enters the board via the SMA Radio connector
* Enters the first Axicom HF3 relay
* The signal is moved to the second Axicom HF3 relay
* Exit to the antenna

## Radio Frequency Performance
### General Specifications
* **System Impedance:** 50 ohms
* **RF Switching Matrix:** Four cascaded pSemi PE4259 ultra-high isolation RF switches
* **Switch Matrix Insertion Loss (Bypass Mode):** ~1.5 dB at 144 MHz; ~3.0 dB to 4.1 dB at 440 MHz
* **System Architecture:** Independent electronic selection for VHF/UHF filter paths and LNA amplification, backed by a hardware-level transmit ground (`TX_GND`) fail-safe bypass

### VHF Bandpass Filter (2-Meter Band)
* **Topology:** 3-pole capacitively-coupled LC bandpass filter built with Johanson High-Q wirewound inductors and C0G low-ESR capacitors
* **Center Frequency Target:** 144.0 MHz – 148.0 MHz
* **Passband Insertion Loss:** 1.33 dB at 144.9 MHz
* **Passband Return Loss (S11):** Better than -10 dB, dipping to -23.7 dB (VSWR 1.13:1)
* **FM Broadcast Rejection (88–108 MHz):** -59 dB to -69.4 dB attenuation. This extreme low-side skirt prevents local 100 kW commercial FM transmitters from driving the active stage into non-linear intermodulation.
* **Aviation Band Rejection (110–130 MHz):** >45 dB of attenuation below 110 MHz

### UHF Bandpass Filter (70-Centimeter Band)
* **Topology:** 2-pole capacitively-coupled LC bandpass filter using Johanson High-Q components
* **Center Frequency Target:** 439.0 MHz (Optimized for Brazilian repeater outputs)
* **Passband Insertion Loss:** 1.05 dB to 1.12 dB at 439.0 MHz
* **Absolute Peak Insertion Loss:** 0.90 dB near 444.0 MHz
* **Impedance Matching:** Utilizes 8.2 pF input/output series matching capacitors to overcome the inherently low characteristic impedance of the 3.9 nH core tanks. This ensures that the ~1 dB of measured loss is strictly reflective mismatch rather than absorptive thermal dissipation, preserving signal integrity before amplification.

### Low Noise Amplifier (LNA) Stage
* **Active Component:** Infineon BFP460 wideband NPN RF transistor
* **Topology:** Wideband shunt-shunt feedback LNA with a passive resistor-divider bias network
* **DC Operating Point:** Conservatively biased at approximately 4 mA Collector Current (Ic) and 3.2V Collector-Emitter Voltage (Vce). This low-power state ensures absolute unconditional stability and preserves the transistor's low intrinsic noise figure (~1.1 dB).
* **Raw Active Gain:** +15 dB to +16 dB broadband gain across both VHF and UHF frequencies
* **Net System Gain (Filter + Matrix + LNA):** +11.97 dB at 144 MHz and +11.90 dB at 439 MHz. The amplifier completely overcomes the combined insertion losses of the passive filters and the 4-stage switch matrix.

## System Protections & Operational Logic

### Hardware & Transmit Protections
SignalSurge is designed to sit directly in the primary RF path of a 50W transceiver. To prevent accidental destruction of the highly sensitive receive components, the board employs multiple layers of hardware-level protection:
* **Fail-Safe RX Architecture:** The primary signal path is controlled by robust Axicom HF3 mechanical relays. Their unpowered, default state is a direct hardware bypass (Antenna -> Radio), ensuring the transceiver can safely transmit even if the board loses power.
* **Transmit Inhibit (`TX_INH`):** When the active RX chain (filters and LNA) is engaged, the board outputs a continuous +13.8V signal to the Yaesu FT-991A's TUN/LIN port. This physically inhibits the radio from transmitting, ensuring 50W of RF is never dumped into the pSemi PE4259 switches (which have a maximum rating of 2W / +33 dBm).
* **Absolute TX Override (`TX_GND`):** Grounding the `TX_GND` line forces the Axicom relays into bypass mode and actively pulls the `ENABLE` line on the 5V regulator low, instantly de-energizing the BFP460 amplifier. This signal trumps all other board logic.
* **ESD & Static Drainage:** Both the antenna and radio ports are guarded by Eaton TVS PolySurge protectors. The antenna port also features a 1 kR resistor and 1000 µH inductor network to bleed off atmospheric static charge before it can reach the solid-state switching matrix.
* **Relay Coil Suppression:** Every mechanical relay coil is isolated with a 100 R current limiting resistor, a parallel 1N4148 flyback diode, and a 0.1 µF decoupling capacitor to suppress inductive voltage spikes during switching.
* **Overcurrent Defense:** The main power rail is protected by a PTC resettable fuse to guard against dead shorts.

### Automated Band Logic & Routing
The board utilizes a hybrid switching approach to maximize both power handling and receive isolation.
* **Solid-State RX Routing:** While the Axicom relays handle the high-power TX bypass, the internal receive path is entirely governed by four pSemi PE4259 RF switches. These provide ultra-high isolation between the VHF filter, UHF filter, and LNA stages without the mechanical wear or contact bounce of traditional relays.
* **Yaesu BCD Integration:** SignalSurge achieves "set-and-forget" automation by reading the BCD encoder outputs from the FT-991A's TUN/LIN port. By monitoring Pin 4 (Band Data B), the board automatically flips the internal solid-state switches between the 144 MHz and 430 MHz bandpass filters exactly as you change bands on the radio dial.
* **Manual Overrides:** Independent +3V header lines for `AMP_ON` and `BYPASS` allow the operator to manually force the LNA on or drop the entire board into hardware bypass.

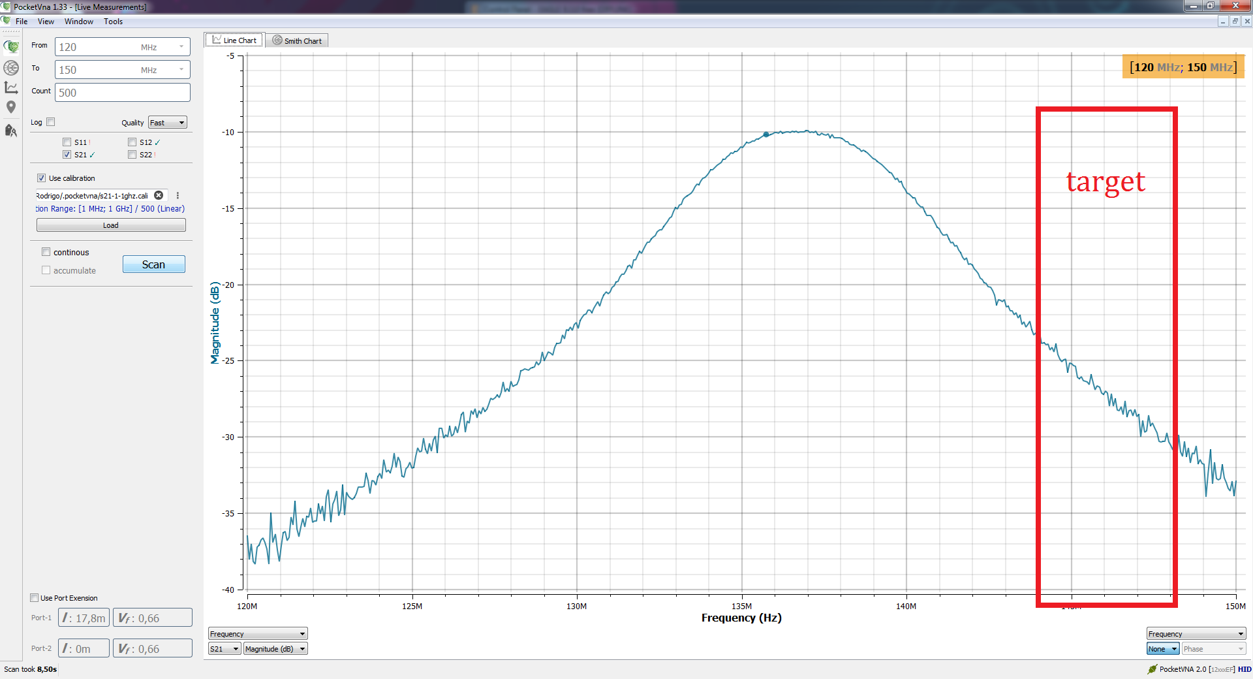
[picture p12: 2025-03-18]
others/test/bpf-vhf-oob-2025-03-13-120-150.png

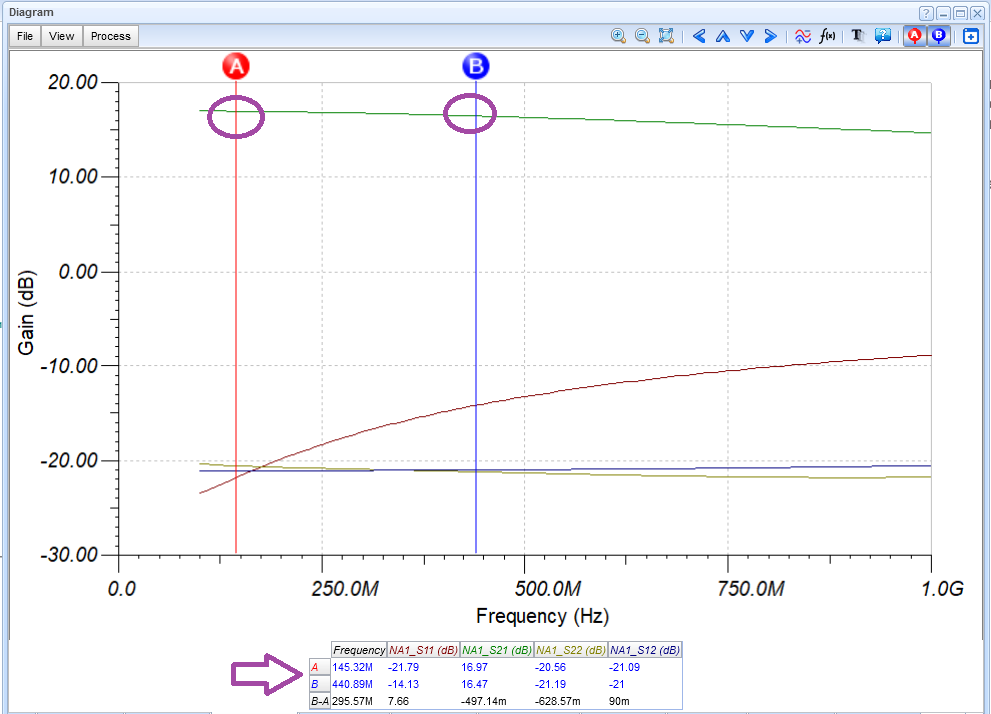
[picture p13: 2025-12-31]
others/test/bfp460-gain-fig.png

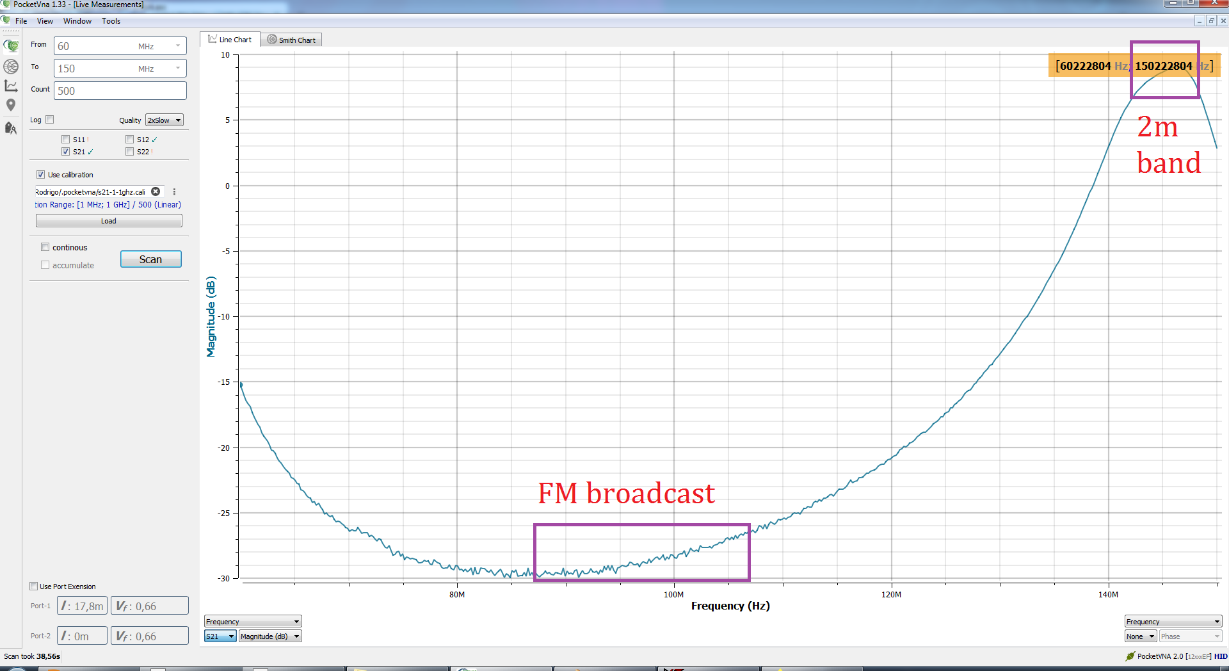
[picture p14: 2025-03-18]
others/test/bpf-vhf-amplified-2025-03-17-60-150.png

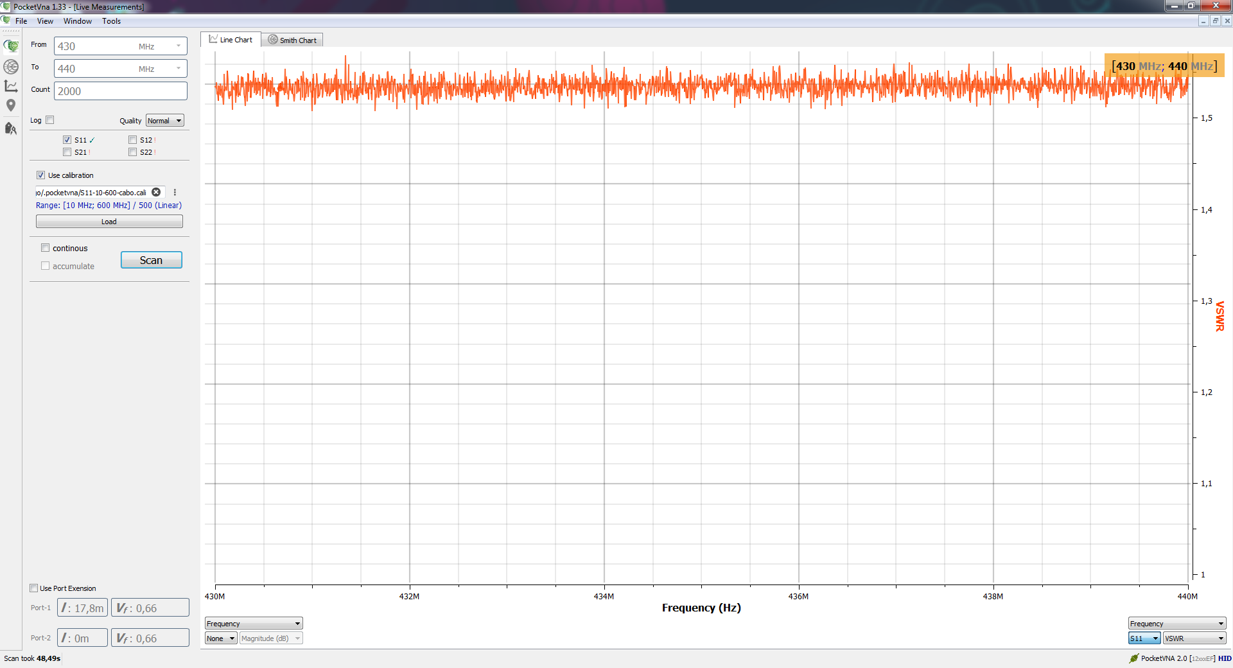
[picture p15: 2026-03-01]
others/test/vswr-430-440.png

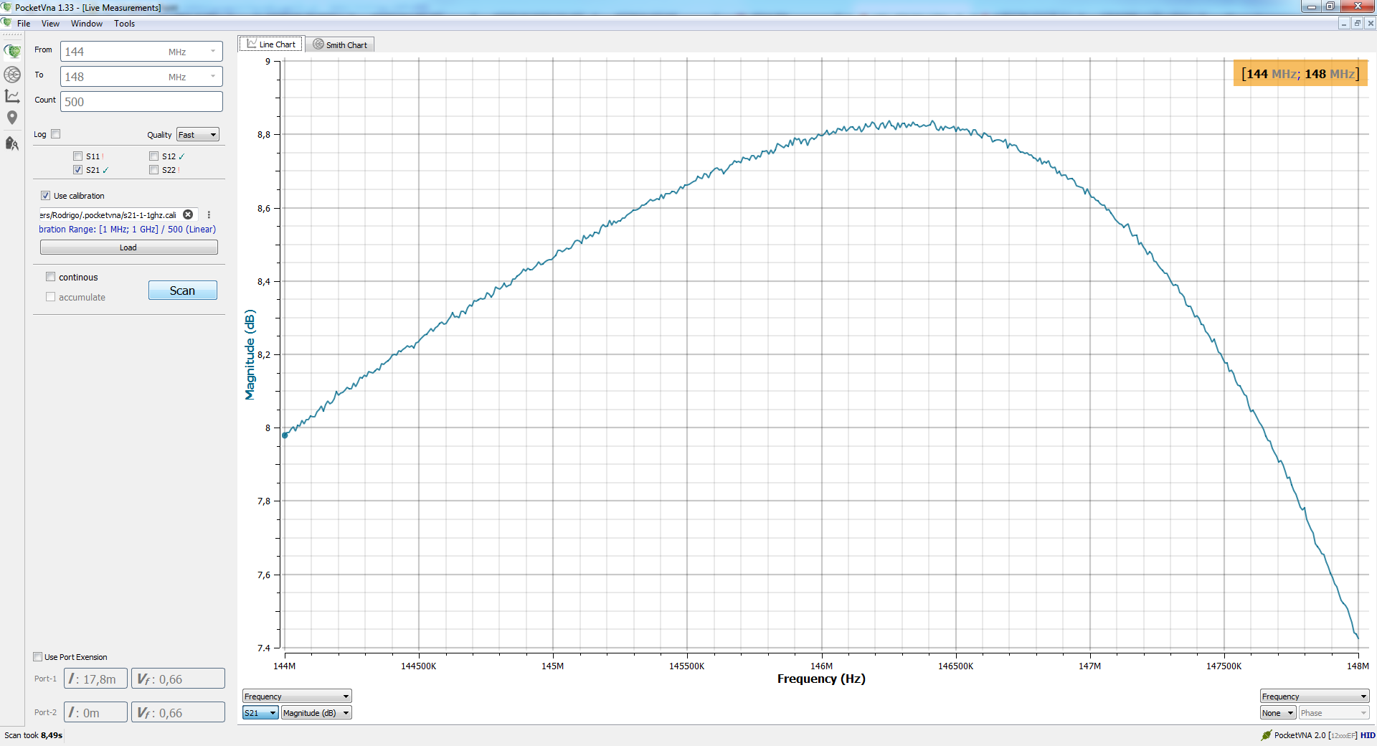
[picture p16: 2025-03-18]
others/test/bpf-vhf-tuned-2025-03-16-144-148.png

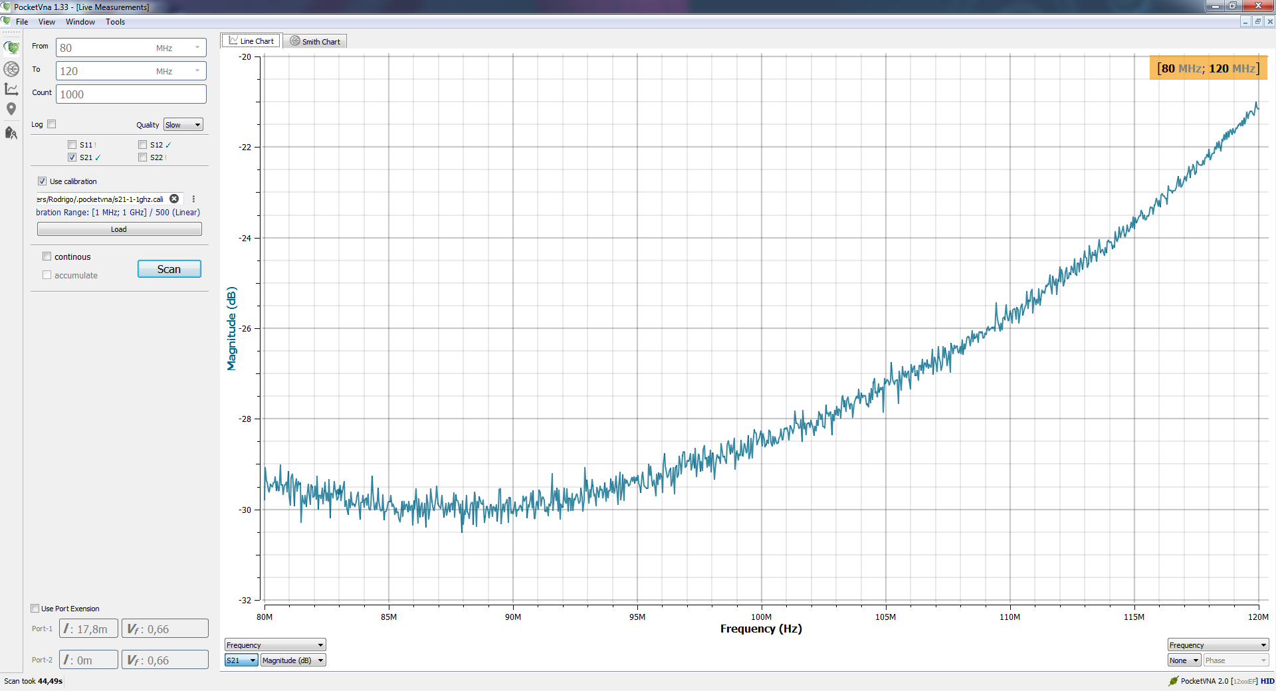
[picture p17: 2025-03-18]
others/test/bpf-vhf-tuned-2025-03-16-80-120.png

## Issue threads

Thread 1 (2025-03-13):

Add u.FL footprint in key areas

rfrht, 2025-03-13:
Add u.FL footprint at:

* Right after relays
* BPF out

rfrht, 2025-05-19:
Done!
1. One at the circuit input
2. one after the BPF
3. one after the amp/circuit output.

Closed 2025-05-19.

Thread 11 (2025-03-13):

Pad VHF BPF CPW

rfrht, 2025-03-13:
The right-side CPW on VHF BPF is too close to the solder pads; some soldered components can short to the ground. Improve spacing.

Closed 2025-05-19.

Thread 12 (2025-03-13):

Change SN74-OR solder pad to the one with longer pads

rfrht, 2025-03-13:
SN74-OR logical gate solder pads are too damn short. Use the same pad as the SN74-AND.

Closed 2025-05-19.

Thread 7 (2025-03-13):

Test relay logic

rfrht, 2025-03-13:
Ensure that the relay logic is sound.

rfrht, 2025-03-18:
Checked the gate configuration and it is sound.

There might be a need for a pulldown resistor on the AMP ON line.

Closed 2025-03-18.

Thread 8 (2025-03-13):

Test electric supply

rfrht, 2025-03-13:
Ensure that the power distribution is sound and correct.

Closed 2025-05-19.

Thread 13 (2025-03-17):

BOM issues

rfrht, 2025-03-17:
The following parts are missing in BOM:

* [BLM21](https://www.digikey.com/en/products/detail/murata-electronics/BLM21AG102SN1D/468922)
* 220 nF (C11)

rfrht, 2025-03-17:
C22 (0.1 µF) footprint is 0805, BOM specifies 1206. Change BOM part to 0805.

rfrht, 2025-03-17:
The following parts are specified but not used:

* [LB3218T102K](https://www.digikey.com/en/products/detail/taiyo-yuden/LB3218T102K/1788933)
* [MLF2012D82NMT000](https://www.digikey.com/en/products/detail/tdk-corporation/MLF2012D82NMT000/504203)

Remove them

Closed 2025-05-19.

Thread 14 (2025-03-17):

Wrong 5V voltage regulator specified

rfrht, 2025-03-17:
The specified L78L05 **does not provide** the Enable functionality - and to add insult to the injury, the footprint is also wrong.

rfrht, 2025-05-19:
Replaced with [Toshiba TCR1HF50B](https://www.digikey.com/en/products/detail/toshiba-semiconductor-and-storage/TCR1HF50B-LM-CT/18875465)

Closed 2025-05-19.

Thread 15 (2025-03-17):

Improve footprint for NCP553

rfrht, 2025-03-17:
NCP553 footprint isn't helpful at all; improve it

rfrht, 2025-05-18:
* Fattened the footprint significantly (to be seen how does that goes)
* Added the pin 1 marker to the middle of pin 1/2.

Closed 2025-05-19.

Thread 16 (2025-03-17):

Improve footprint for UMD5N

rfrht, 2025-03-17:
* Put the pin 1 dot in a more legible place (it's a stripe)
* Increase the pad size

rfrht, 2025-05-18:
* Moved dot to a more external place
* Increased pad size
* Added a stripe in the pin 1/6 side

Closed 2025-05-19.

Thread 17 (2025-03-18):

Double-check UMD5N connections

rfrht, 2025-03-18:
After soldering the UMD5N the PTC fuse triggered and the board went in undervoltage.

Double-check:

- Component footprint
- Component schematic
- Implementation on the board

rfrht, 2025-05-18:
The component was set up wrongly in the original schematic - flipped 180 degree. Shit all around.
Fixed.

Closed 2025-05-19.

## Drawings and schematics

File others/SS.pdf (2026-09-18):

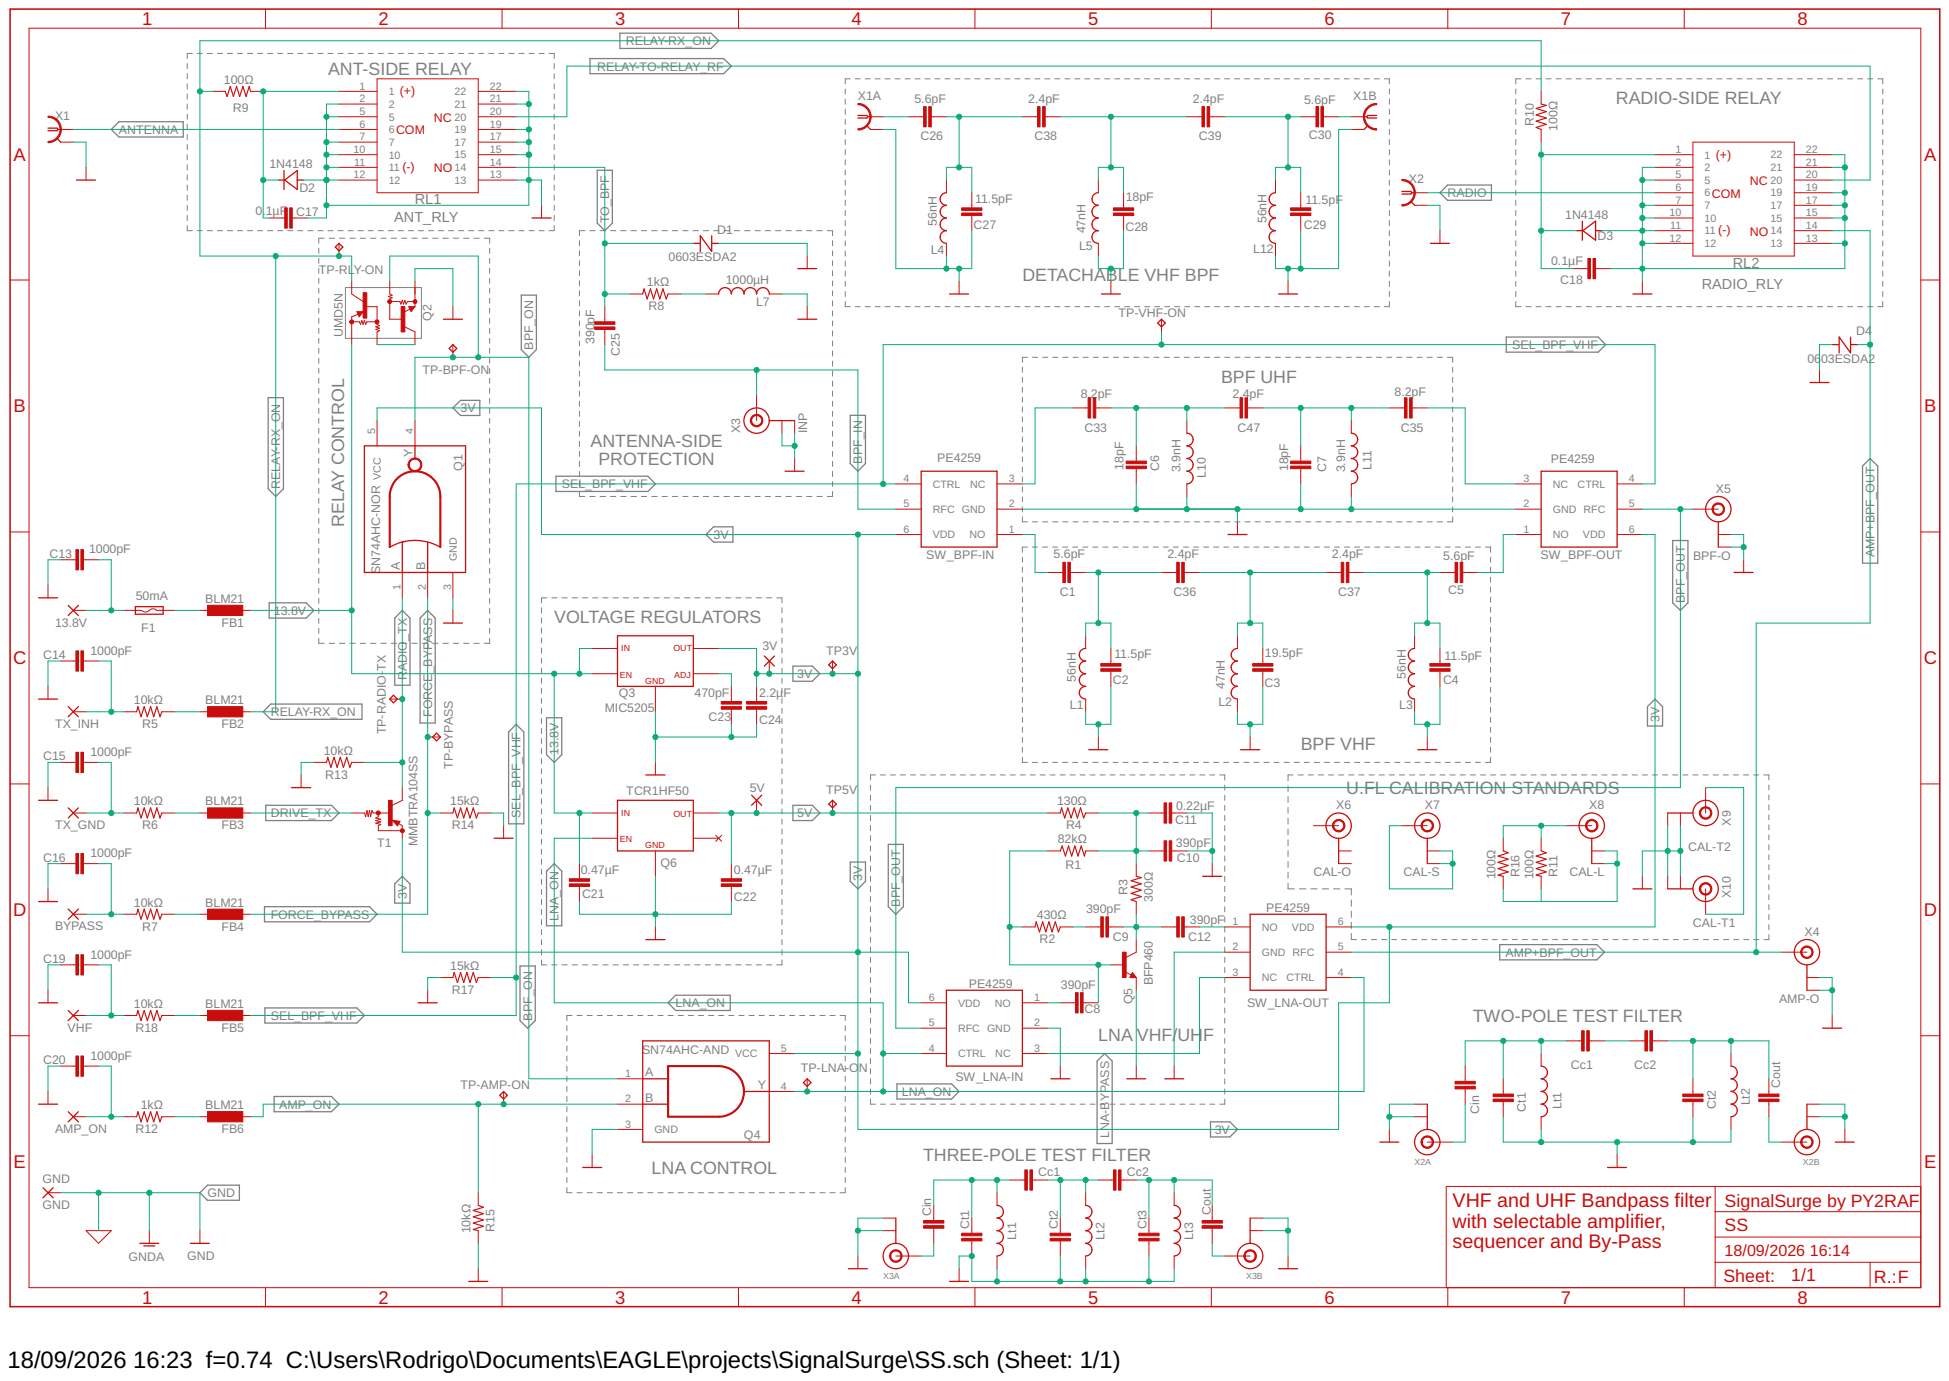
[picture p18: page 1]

5 | 20
6 7 | 19

6 | 19
7 | 17
10 | 15
11 12 | 14

TWO-POLE TEST FILTER

THREE-POLE TEST FILTER

VHF and UHF Bandpass filter with selectable amplifier, sequencer and By-Pass

18/09/2026 16:23 f=0.74 C:\Users\Rodrigo\Documents\EAGLE\projects\SignalSurge\SS.sch (Sheet: 1/1)

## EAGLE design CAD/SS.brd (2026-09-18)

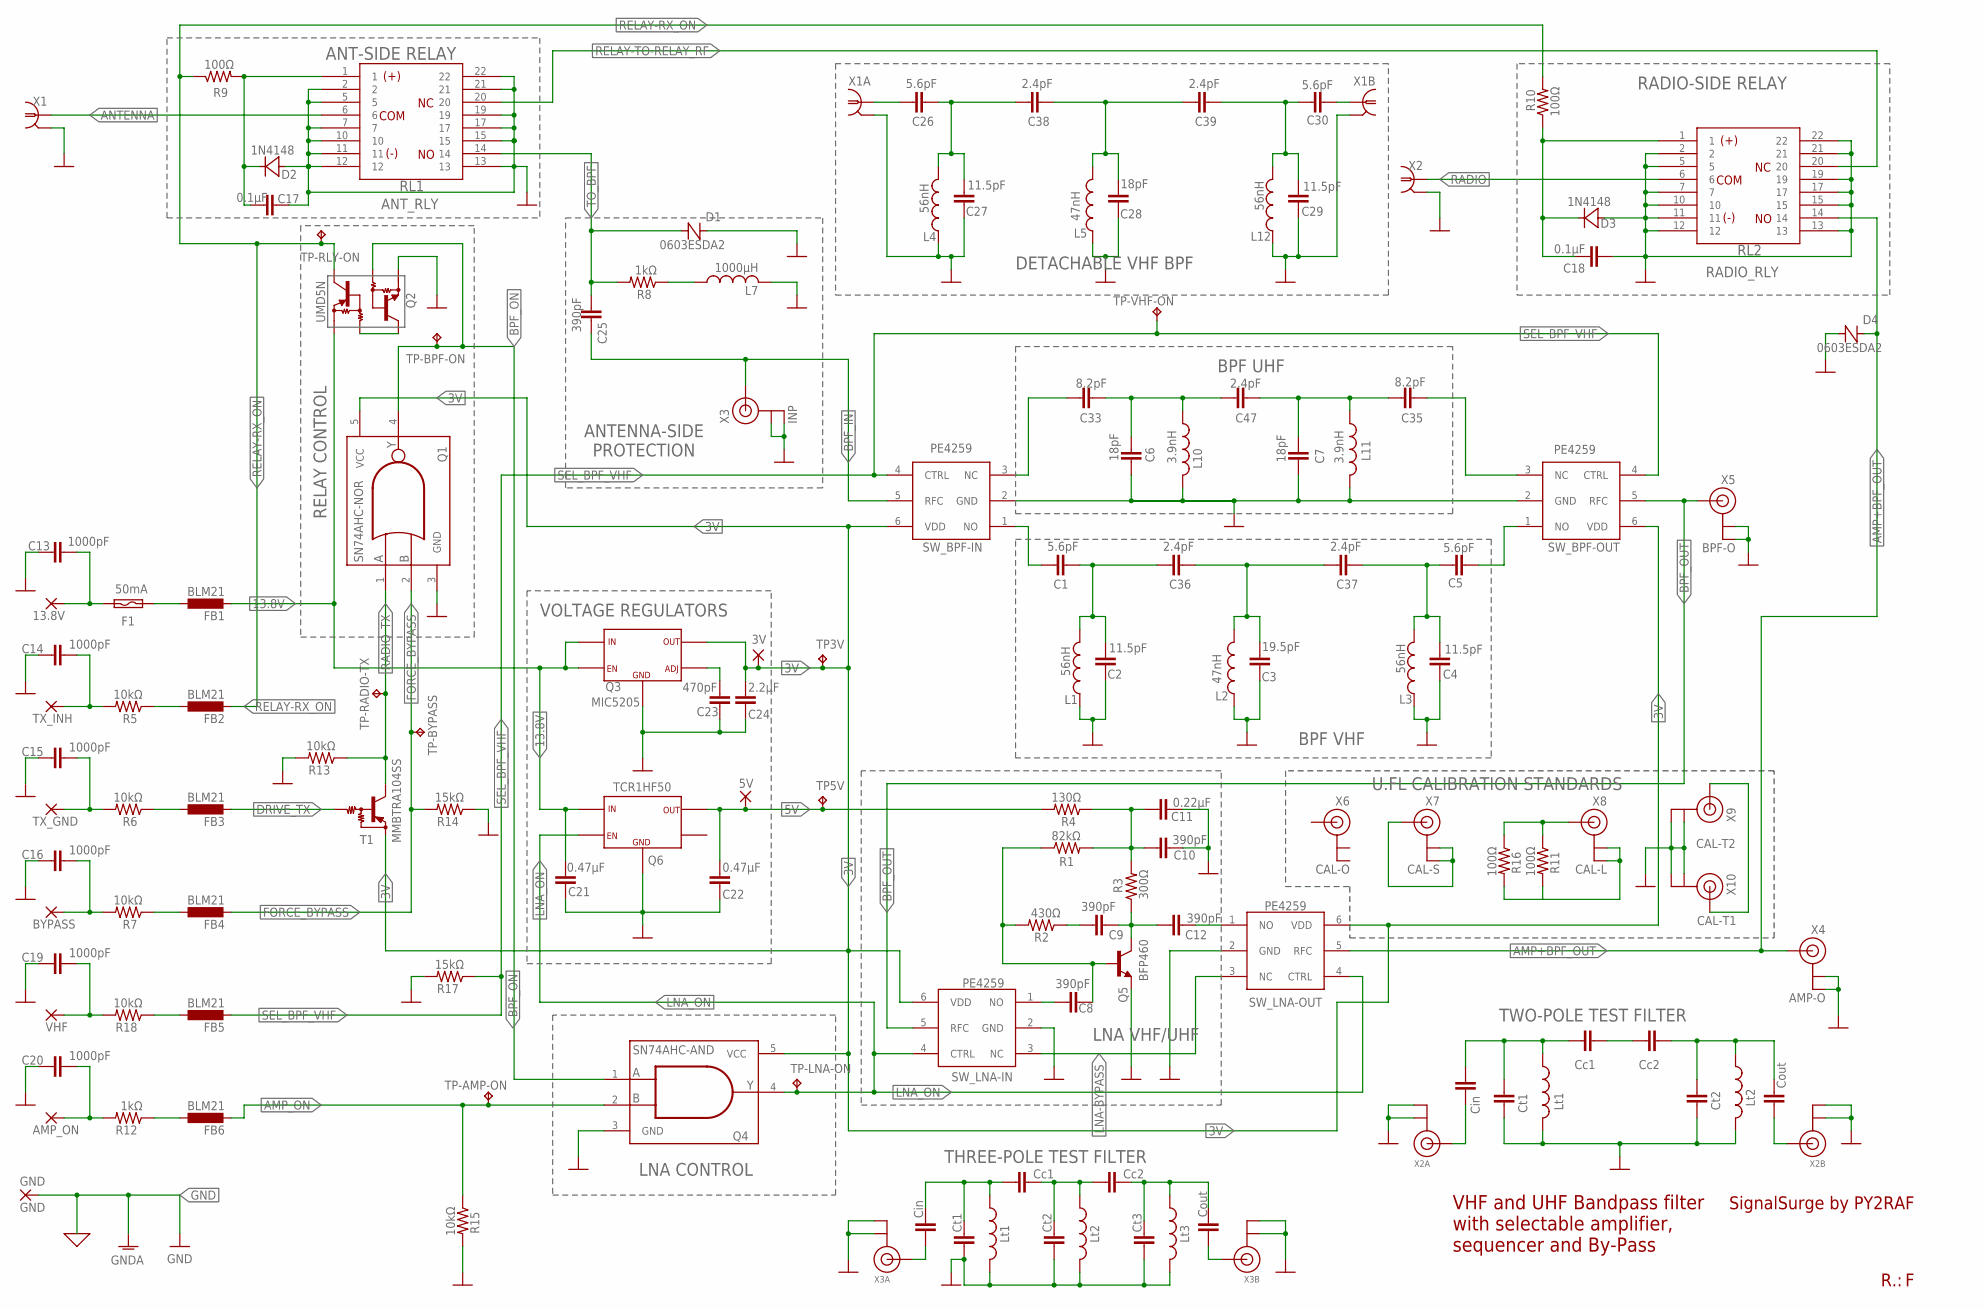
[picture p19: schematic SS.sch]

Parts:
3V: 3V; JUMPER1
5V: 5V; JUMPER1
13.8V: 13.8V; JUMPER1
AMP_ON: AMP_ON; JUMPER1
BYPASS: BYPASS; JUMPER1
C1, C5, C26, C30: 5.6pF; 0805
C2, C4, C27, C29: 11.5pF; 0805
C3: 19.5pF; 0805
C6, C7, C28: 18pF; 0805
C8, C9, C10, C12, C25: 390pF; 0805
C11: 0.22µF; 0805
C13, C14, C15, C16, C19, C20: 1000pF; 0805
C17, C18: 0.1µF; 0805
C21, C22: 0.47µF; 0805
C23: 470pF; 0805
C24: 2.2µF; 0805
C31, C41: Ct1; 0805
C32, C43: Ct2; 0805
C33, C35: 8.2pF; 0805
C36, C37, C38, C39, C47: 2.4pF; 0805
C40: Cin; 0805
C42: Cc1; 0805
C44: Cc2; 0805
C45: Ct3; 0805
C46: Cout; 0805
D1, D4: 0603ESDA2; 0603
D2, D3: 1N4148; SOD-323
F1: 50mA; FUSE-1206
FB1, FB2, FB3, FB4, FB5, FB6: BLM21; 0805
GND: GND; JUMPER1
L1, L3, L4, L12: 56nH; 0805
L2, L5: 47nH; 0805
L6, L16: Lt1; 0805
L7: 1000µH; 1207
L8, L17: Lt2; 0805
L9: Lt3; 0805
L10, L11: 3.9nH; 0805
L13: Cc2; 0805
L14: Cout; 0805
L15: Cin; 0805
L18: Cc1; 0805
Q1: SN74AHC-NOR; SC70-5
Q2: UMD5N; SOT363
Q3: MIC5205; SOT23-5
Q4: SN74AHC-AND; SC70-5
Q5: BFP460; SOT343R
Q6: TCR1HF50; SC-74A
R1: 82kΩ; 1206
R2: 430Ω; 1206
R3: 300Ω; 1206
R4: 130Ω; 1206
R5, R6, R7, R13, R15, R18: 10kΩ; 1206
R8, R12: 1kΩ; 1206
R9, R10, R11, R16: 100Ω; 1206
R14, R17: 15kΩ; 1206
RL1: ANT_RLY; RELAY-TE-HF3
RL2: RADIO_RLY; RELAY-TE-HF3
SW_BPF-IN: PE4259; SC-70
SW_BPF-OUT: PE4259; SC-70
SW_LNA-IN: PE4259; SC-70
SW_LNA-OUT: PE4259; SC-70
T1: MMBTRA104SS; SC59-BEC
TP3V, TP5V: TPB1,27; B1,27
TP-AMP-ON: TPB1,27; B1,27
TP-BPF-ON: TPB1,27; B1,27
TP-BYPASS: TPB1,27; B1,27
TP-LNA-ON: TPB1,27; B1,27
TP-RADIO-TX: TPB1,27; B1,27
TP-RLY-ON: TPB1,27; B1,27
TP-VHF-ON: TPB1,27; B1,27
TX_GND: TX_GND; JUMPER1
TX_INH: TX INH; JUMPER1
VHF: VHF; JUMPER1
X1: ANTENNA; SMA-RF
X1A, X1B: SMA-EDGE
X2: RADIO; SMA-RF
X2A, X2B, X3A, X3B: ANTENNA_U.FL; U.FL
X3: INP; U.FL
X4: AMP-O; U.FL
X5: BPF-O; U.FL
X6: CAL-O; U.FL
X7: CAL-S; U.FL
X8: CAL-L; U.FL
X9: CAL-T2; U.FL
X10: CAL-T1; U.FL

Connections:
3V: 3V.1, C24.P$2 (2), Q1.5 (VCC), Q3.5 (VOUT), Q4.5 (VCC), SW_BPF-IN.6 (VDD), SW_BPF-OUT.6 (VDD), SW_LNA-IN.6 (VDD), SW_LNA-OUT.6 (VDD), T1.E, TP3V.TP
5V: 5V.1, C22.P$2 (2), Q6.5 (VOUT), R4.2, TP5V.TP
13.8V: C21.P$2 (2), FB1.P$2 (2), Q2.4 (6), Q3.1 (VIN), Q3.3 (EN), Q6.1 (VIN)
13.8V_IN: 13.8V.1, C13.P$2 (2), F1.2
AMP+BPF_OUT: D4.1 (A), RL2.14, SW_LNA-OUT.5 (RFC), X4.3 (SIGNAL)
AMP_ON: FB6.P$2 (2), Q4.2 (B), R15.1, TP-AMP-ON.TP
AMP_ON_IN: AMP_ON.1, C20.P$2 (2), R12.2
ANTENNA: RL1.6, X1.1
BIAS_IN: C10.P$1 (1), C11.P$1 (1), R1.2, R3.2, R4.1
BLEED: L7.P$1 (1), R8.1
BPF_IN: C25.P$1 (1), SW_BPF-IN.5 (RFC), X3.3 (SIGNAL)
BPF_ON: Q1.4 (Y), Q2.2, Q4.1 (A), TP-BPF-ON.TP
BPF_OUT: SW_BPF-OUT.5 (RFC), SW_LNA-IN.5 (RFC), X5.3 (SIGNAL)
BYPASS_SEL_IN: BYPASS.1, C16.P$2 (2), R7.2
D-V-IN: C30.P$2 (2), X1B.P$3 (1)
D-V-OUT: C26.P$2 (2), X1A.P$3 (1)
D-V-P1: C26.P$1 (1), C27.P$1 (1), C38.P$2 (2), L4.P$2 (2)
D-V-P2: C28.P$1 (1), C38.P$1 (1), C39.P$2 (2), L5.P$2 (2)
D-V-P3: C29.P$1 (1), C30.P$1 (1), C39.P$1 (1), L12.P$1 (1)
DRIVE_TX: FB3.P$2 (2), T1.B
FEED-RA: C17.P$2 (2), D2.C, R9.2, RL1.1
FEED-RB: C18.P$1 (1), D3.C, R10.1, RL2.1
FORCE_BYPASS: FB4.P$2 (2), Q1.2 (B), R14.2, TP-BYPASS.TP
GND: C2.P$2 (2), C3.P$2 (2), C4.P$2 (2), C6.P$1 (1), C7.P$1 (1), C10.P$2 (2), C11.P$2 (2), C13.P$1 (1), C14.P$1 (1), C15.P$1 (1), C16.P$1 (1), C17.P$1 (1), C18.P$2 (2), C19.P$1 (1), C20.P$1 (1), C21.P$1 (1), C22.P$1 (1), C23.P$1 (1), C24.P$1 (1), C27.P$2 (2), C28.P$2 (2), C29.P$2 (2), C31.P$1 (1), C32.P$1 (1), C41.P$2 (2), C43.P$2 (2), C45.P$2 (2), D1.1 (A), D2.A, D3.A, D4.2 (C), GND.1, L1.P$1 (1), L2.P$1 (1), L3.P$2 (2), L4.P$1 (1), L5.P$1 (1), L6.P$2 (2), L7.P$2 (2), L8.P$2 (2), L9.P$2 (2), L10.P$2 (2), L11.P$2 (2), L12.P$2 (2), L16.P$2 (2), L17.P$2 (2), Q1.3 (GND), Q2.1, Q3.2 (GND), Q4.3 (GND), Q5.1 (E), Q5.3 (E), Q6.2 (GND), R13.2, R14.1, R15.2, R17.2, RL1.2, RL1.5, RL1.7, RL1.10, RL1.11, RL1.12, RL1.13, RL1.15, RL1.17, RL1.19, RL1.21, RL1.22, RL2.2, RL2.5, RL2.7, RL2.10, RL2.11, RL2.12, RL2.13, RL2.15, RL2.17, RL2.19, RL2.21, RL2.22, SW_BPF-IN.2 (GND), SW_BPF-OUT.2 (GND), SW_LNA-IN.2 (GND), SW_LNA-OUT.2 (GND), X1.2, X1.3 (2), X1.4 (2), X1.5 (2), X1A.P$1 (2), X1A.P$2 (2), X1A.P$4 (2), X1A.P$5 (2), X1A.P$6 (2), X1A.P$7 (2), X1B.P$1 (2), X1B.P$2 (2), X1B.P$4 (2), X1B.P$5 (2), X1B.P$6 (2), X1B.P$7 (2), X2.2, X2.3 (2), X2.4 (2), X2.5 (2), X2A.1 (GND), X2A.2 (GND), X2B.1 (GND), X2B.2 (GND), X3.1 (GND), X3.2 (GND), X3A.1 (GND), X3A.2 (GND), X3B.1 (GND), X3B.2 (GND), X4.1 (GND), X4.2 (GND), X5.1 (GND), X5.2 (GND), X9.1 (GND), X9.2 (GND), X10.1 (GND), X10.2 (GND)
LNA-BYPASS: SW_LNA-IN.3 (NC), SW_LNA-OUT.3 (NC)
LNA-IN: C8.P$2 (2), Q5.4 (B), R1.1, R2.2
LNA-OUT: C9.P$2 (2), C12.P$1 (1), Q5.2 (C), R3.1
LNA_ON: Q4.4 (Y), Q6.3 (EN), SW_LNA-IN.4 (CTRL), SW_LNA-OUT.4 (CTRL), TP-LNA-ON.TP
unnamed: C12.P$2 (2), SW_LNA-OUT.1 (NO)
unnamed: C8.P$1 (1), SW_LNA-IN.1 (NO)
unnamed: C23.P$2 (2), Q3.4 (ADJ-BYP)
unnamed: L13.P$1 (1), L18.P$2 (2)
unnamed: L15.P$1 (1), X2A.3 (SIGNAL)
unnamed: Q2.5, Q2.6 (4)
unnamed: X7.1 (GND), X7.2 (GND), X7.3 (SIGNAL)
unnamed: R11.1, R16.1, X8.3 (SIGNAL)
unnamed: R11.2, R16.2, X8.1 (GND), X8.2 (GND)
unnamed: L14.P$2 (2), X2B.3 (SIGNAL)
unnamed: FB5.P$1 (1), R18.1
unnamed: F1.1, FB1.P$1 (1)
unnamed: X9.3 (SIGNAL), X10.3 (SIGNAL)
unnamed: C9.P$1 (1), R2.1
unnamed: FB2.P$1 (1), R5.1
unnamed: FB3.P$1 (1), R6.1
unnamed: FB4.P$1 (1), R7.1
unnamed: FB6.P$1 (1), R12.1
RADIO: RL2.6, X2.1
RADIO_TX: Q1.1 (A), R13.1, T1.C, TP-RADIO-TX.TP
RELAY-RX_ON: FB2.P$2 (2), Q2.3, R9.1, R10.2, TP-RLY-ON.TP
RELAY-TO-RELAY_RF: RL1.20, RL2.20
SEL_BPF_VHF: FB5.P$2 (2), R17.1, SW_BPF-IN.4 (CTRL), SW_BPF-OUT.4 (CTRL), TP-VHF-ON.TP
T-U-IN: C40.P$1 (1), X3A.3 (SIGNAL)
T-U-OUT: C46.P$1 (1), X3B.3 (SIGNAL)
T-U-P1: C40.P$2 (2), C41.P$1 (1), C42.P$1 (1), L6.P$1 (1)
T-U-P2: C42.P$2 (2), C43.P$1 (1), C44.P$1 (1), L8.P$1 (1)
T-U-P3: C44.P$2 (2), C45.P$1 (1), C46.P$2 (2), L9.P$1 (1)
T-V-P1: C31.P$2 (2), L15.P$2 (2), L16.P$1 (1), L18.P$1 (1)
T-V-P2: C32.P$2 (2), L13.P$2 (2), L14.P$1 (1), L17.P$1 (1)
TO_BPF: C25.P$2 (2), D1.2 (C), R8.2, RL1.14
TX_GND_IN: C15.P$2 (2), R6.2, TX_GND.1
TX_INH_OUT: C14.P$2 (2), R5.2, TX_INH.1
UHF-IN: C33.P$1 (1), SW_BPF-IN.3 (NC)
UHF-OUT: C35.P$2 (2), SW_BPF-OUT.3 (NC)
UHF-P1: C6.P$2 (2), C33.P$2 (2), C47.P$1 (1), L10.P$1 (1)
UHF-P2: C7.P$2 (2), C35.P$1 (1), C47.P$2 (2), L11.P$1 (1)
VHF-IN: C1.P$2 (2), SW_BPF-IN.1 (NO)
VHF-OUT: C5.P$2 (2), SW_BPF-OUT.1 (NO)
VHF-P1: C1.P$1 (1), C2.P$1 (1), C36.P$2 (2), L1.P$2 (2)
VHF-P3: C4.P$1 (1), C5.P$1 (1), C37.P$1 (1), L3.P$1 (1)
VHF_ON_IN: C19.P$2 (2), R18.2, VHF.1
VPF-P2: C3.P$1 (1), C36.P$1 (1), C37.P$2 (2), L2.P$2 (2)

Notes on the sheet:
BPF UHF
BPF VHF
LNA VHF/UHF
RELAY CONTROL
RADIO-SIDE RELAY
VOLTAGE REGULATORS
SignalSurge by PY2RAF
R.:
VHF and UHF Bandpass filter with selectable amplifier, sequencer and By-Pass
ANTENNA-SIDE PROTECTION
LNA CONTROL
ANT-SIDE RELAY
DETACHABLE VHF BPF
TWO-POLE TEST FILTER
THREE-POLE TEST FILTER
U.FL CALIBRATION STANDARDS

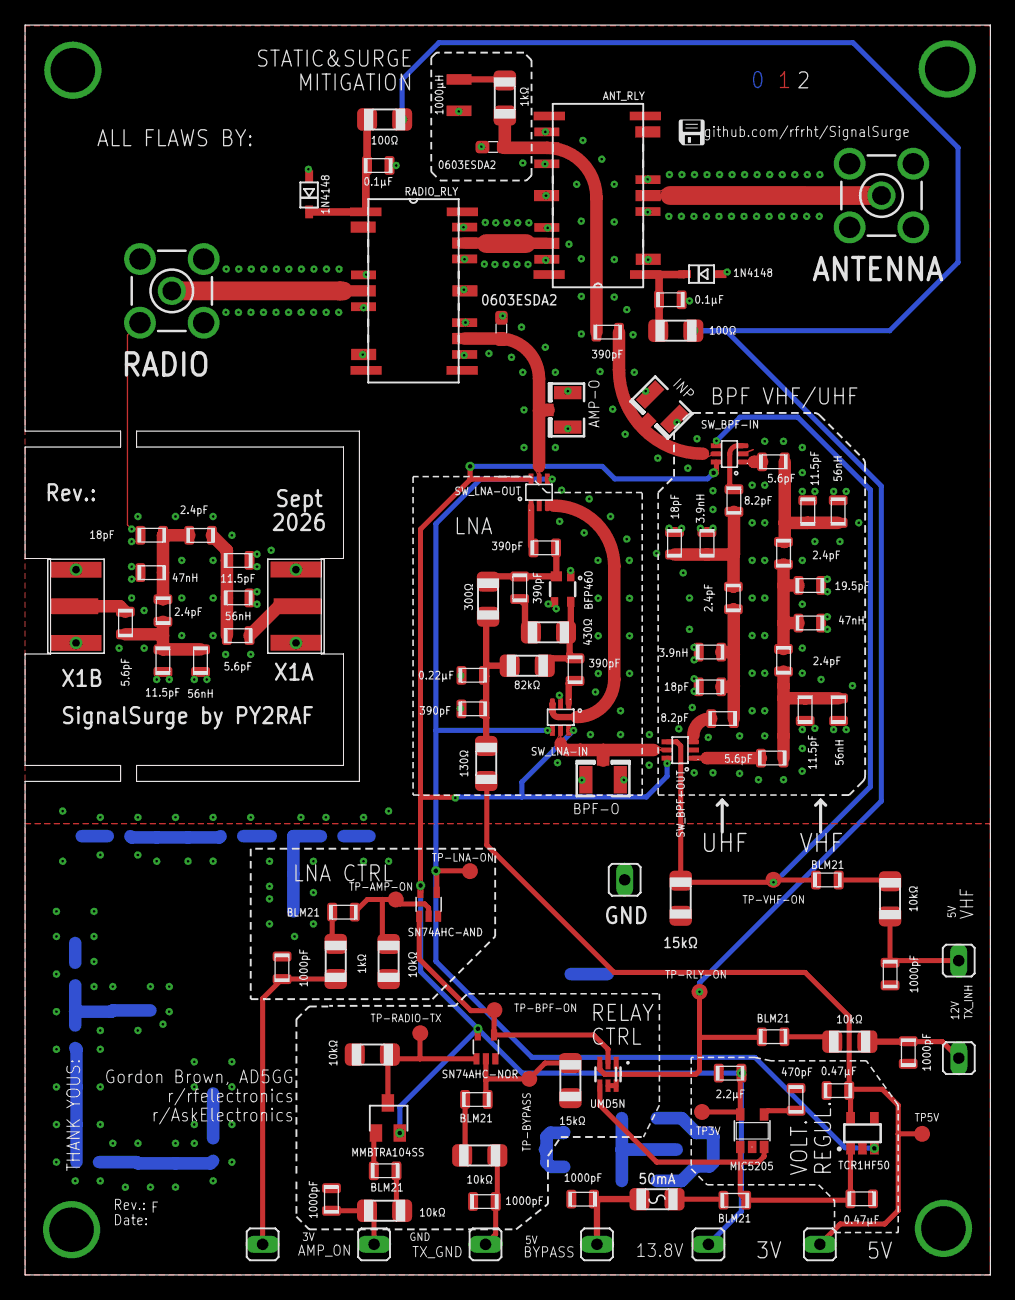
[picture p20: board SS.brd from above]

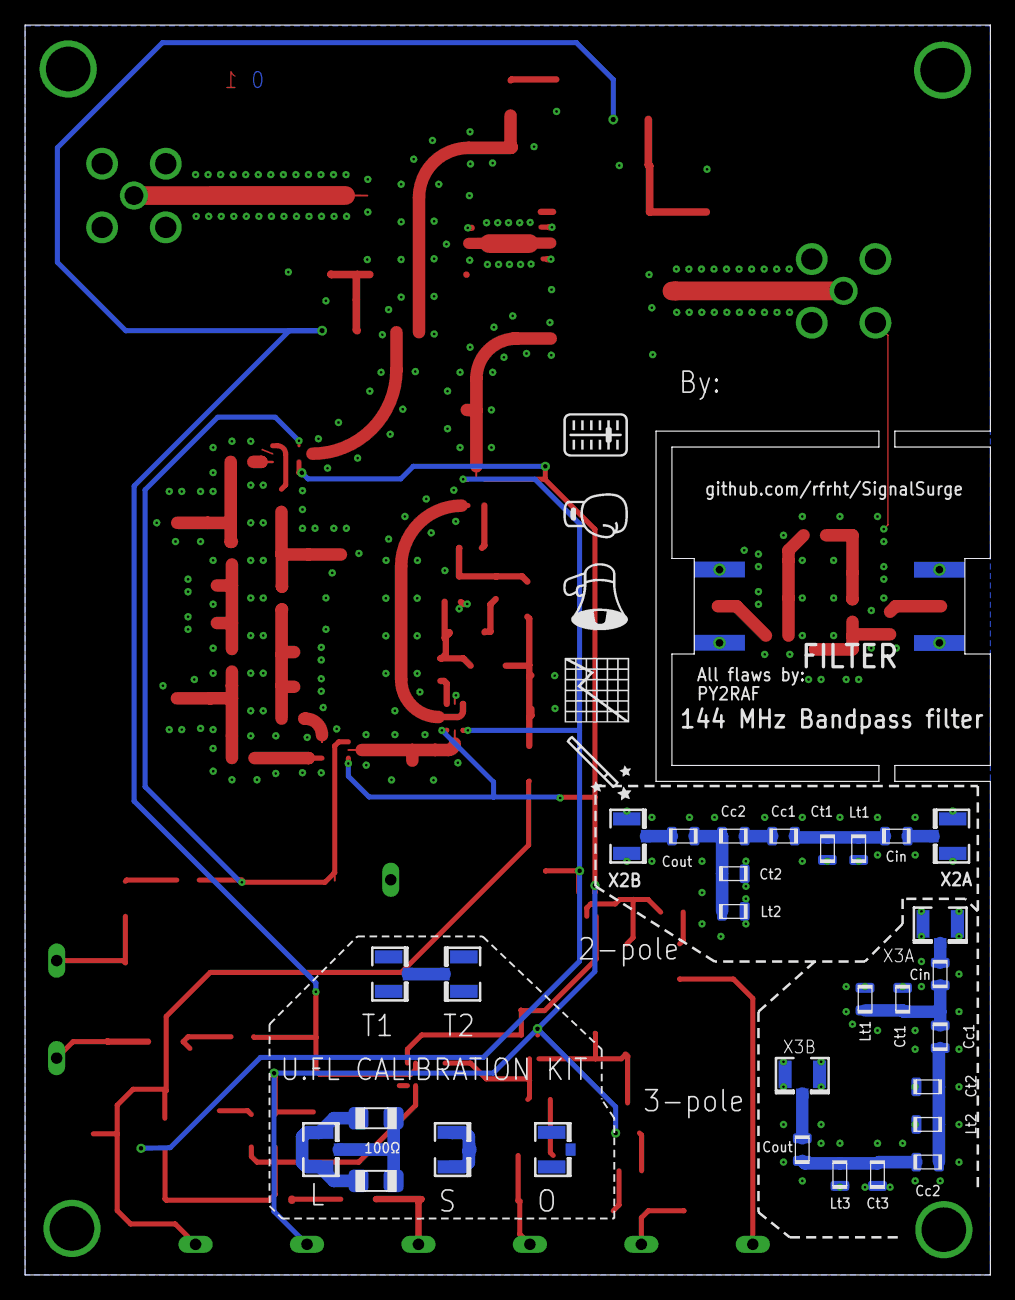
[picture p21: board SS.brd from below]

Board: 2 copper layers, 77.0 x 99.7 mm, 140 parts (29 on the bottom side), 71 nets.

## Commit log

2024-11-27 Add files via upload
    Initial commit - PDF, Schematic and Board.
    [SS.brd, SS.sch]
2024-11-28 Changed the isolation circuitry
    Tip by [u/Nu2Denim/](https://www.reddit.com/user/Nu2Denim/) at [r/rfelectronics](https://www.reddit.com/r/rfelectronics/comments/1h0pffq/help_me_reuse_this_circuit/)
    [SS.sch]
2024-12-02 Small minor improvements
    * Corrected position of surge arrestor
    * Added description for some networks
    * Small improvements in component placement
    [SS.brd, SS.sch]
2024-12-10 More updates - refinements
    * Added RF relays
    * Simplified to a single relay driver (more than enough oomph to drive them both)
    * New PNP-based driver for TX_GND
    * Copious amount of signal direction and comments
    [SS.brd, SS.sch]
2024-12-11 Progress.
    Schematic:
    * Added pulldown resistors to input ports at OR comparator
    * Added static bleeding on antenna-side isolation
    * Replaced some 1206 caps with 0805
    Board:
    * Started arranging the first components.
    [SS.brd, SS.sch]
2024-12-11 Better directory hierarchy
    [SS.brd, SS.sch]
2024-12-14 Fix resistor feed for relays
    100R relay resistors were in a wrong place.
2024-12-14 Board: Pouring some copper over it
    Started designing the board layout.
    Plus, schematic: Fixed an error on 100R relay resistor placement
    [SS.brd, SS.sch]
2024-12-17 More copper poured
    [SS.brd, SS.sch]
2024-12-19 Progress
    - Replaced capacitors and resistors with ones who has a PCB marking
    - Poured more copper
    - Added annotations
    - Some block relocations
    [SS.brd, SS.sch]
2024-12-19 New files: The first board images
2024-12-19 More progress
    - Featuring: CPWs (check https://resources.altium.com/p/pros-and-cons-of-different-high-frequency-transmission-line-types)
    - Revamped BPF component layout
    - Serious routing in RF side
    - More labeled signals
    Getting closer to the real deal
    [SS.brd, SS.sch]
2024-12-20 Fixed crass error on LNA RF switch
    it was flipped the ports RF1/RF2 (NO/NC)
    [SS.brd, SS.sch]
2024-12-22 Readme: More documentation
    Added relay logic part
2024-12-22 Fixed relay/switch logics
    * REviewed thoroughly the relay logic and connectors.
    * Had to add a new "NOR" part. Complexity wins...
    * Re-routed 5V regulator Enable pin to LNA logic
    [SS.brd, SS.sch]
2024-12-22 Updated schematic.
2024-12-22 Updates to Board & Schematics
    * Added pads for 3V and 5V
    * Added signal direction on signal pads
    * Added a lot of gimmicks
    * Added exposed copper so I can try the effects of covering some RF-critical sections with copper tape
    * Reviewed some component position
    * More comments
    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
    [SS.brd, SS.sch]
2024-12-22 Updated board image file and schematic
2025-01-07 SignalSurge: Several improvements (check comment for details)
    * Changed the VHF BPF topology, using an impedance transformer to
    use a 1000 ohm-calculated BPF, yielding less critical component values
    * Small improvements in BPF CPWs
    * Implemented some changes suggested at r/rfElectronics
    [SS.brd, SS.sch]
2025-01-07 More improvements, check the commit comment
    - Fixed BFR460 footprint (it was VERY wrong)
    - Zeroed the DRC warnings
    - Added rastnest stop on some large RF-involved components
    - Named few signal lines
    - Improved identification of Pin 1 of RF switches
    - Added Test Points
    - Better component identification
    [SS.brd, SS.sch]
2025-01-07 New: BOM. And minor improvements (more in comments)
    - Added a BOM
    - Changed L7 footprint to match the Tayo proprietary (1207 footprint)
    - Another round of DRC check
    [SS.brd, SS.csv, SS.sch]
2025-02-18 Gerber: Adding initial release
2025-02-19 Board: Shrinked board a bit to fit JLCPCB $2 tier
    Board was a bit larger than 10 cm, shrinked it to fit to the $2 tier
    Also; updated README
    [SS.brd]
2025-03-12 Added capacitor kit image
2025-05-19 Update SS.csv
    Resolves #13
    Fixes:
    - Capacitor footprints
    - Brought back BLM21 from Murata
    - Fixed wrong cap values
    - Double-checked capacitor values, prices and max voltage
    [SS.csv]
2025-05-19 BOM: Replaced SO239 to SMA connectors
    [SS.csv]
2025-05-19 Update SS.csv
    Added u.FL connectors
    Relates to: #1
    [SS.csv]
2025-05-19 Starring: Rev. B
    Resolves: #1 #2 #4 #5 #10 #11 #12 #13 #14 #15 #16 #17
    In a nutshell:
    - Fixed UMD5N placement issue
    - Improved UMD5N footprint
    - Improved NCP553 footprint
    - Improved SN74-OR footprint
    - Changed connectors to SMA
    - Fixed the 5V voltage regulator
    - Fixed lotsa BOM errors
    - Improved and recalculated coplanar waveguide
    - Updated VHF BPF component values
    - Added a TP for VHF BPF
    - Added three u.FL connectors/pads to help debugging
    - Pretty much this is it!
    [SS.brd, SS.sch]
2025-05-21 Fixed BOM component values
    C24 spec 0.33µF, BOM had 0.033µF
    Removed unreferenced cap C22 in 0.1µF line
    [SS.csv]
2025-07-09 Revision B updates
    - Added a detachable board (taking advantage of the spare board real estate) that fits a RTL-SDR Bandpass filter.
    - Minor signal and label revisions, routing
    - Better labeling for signal I/O by adding expected voltages, improved semiotics
    - Tentatively final.
    [SS.brd, SS.csv, SS.sch]
2025-07-09 Update BOM
    Added SMA Edge connectors for detachable board
    [SS.csv]
2025-07-10 Minor board fixes
    - Removed some vias that can be problematic around RF switches
    - Fixed silkscreen issues on I/O pads
    [SS.brd]
2025-07-10 Board: Changed pads to jumpers
    Why I didn't do it before, doh. Pads are... Complicated.
    Also:
    - Changed the silk of the fuse (now with value)
    - Relabeled the region around the jumper
    [SS.brd, SS.sch]
2025-07-14 Board: Minor improvements
    - Better GND labeling
    - Cleared area around BFP460 solder footprint
    [SS.brd]
2025-08-20 Board: Fixed cut boundaries for daughterboard
    The detachable daughterboard wasn't being properly picked by
    JLCPCB (was using layer 46 to define the cut areas)
    Changed the cut sections to layer 20 and fixed it.
    [SS.brd]
2025-08-31 Rev. B: Improvements
    * Added pulldown lines in comparators
    * Routing change on the back of the board
    * Unified logic ICs into SC70-5 footprint
    * Updated BOM to add new pulldown resistors - fixed wrong 0.22µf part (it was 0.022µf) in BOM
    * Better footprint for BFP460 and NCP553
    [SS.brd, SS.csv, SS.sch]
2025-08-31 BOM: fixed wrong 0.22µF capacitor part ID
    [SS.csv]
2025-09-01 Board: Fixed cut area in daughter board
    [SS.brd]
2025-12-26 BOM: Updated 390pF cap
    [SS.csv]
2025-12-29 Revision C: Initial launch
    For more information, check the changelog.
    [SS.brd, SS.sch]
2025-12-30 Gerber: Minor fixes
    - Replaced some vias that were bleeding into the keepout zone
2025-12-30 Board: Refactored the CPWs
    [SS.brd]
2025-12-30 Board image: Uploaded updated layout
2025-12-30 Adding miniature filters
2025-12-30 Better images for miniature filter
2025-12-30 README: Warning for not transmit over the filter.
2025-12-31 Finished board: Updated image
2026-02-22 Now: Revision D!
    - This is now production grade
    - Fixed the pesky UMD5N footprint issue
    - Documented thoroughly the BPF and Amplifier performance
    - Decoupled the relay logic markdown
    - Changed pulldowns on 74XX to 100kR
    - More silkscreen, ink for the win
    - Resolves: #6, #23, #24
    [SS.brd, SS.csv, SS.sch]
2026-02-23 Added specifications
    Added specifications for power consumption, signal routing, and radio frequency performance for VHF and UHF.
2026-02-23 Added 70 cm band sweep
2026-02-23 Update README with correct links for bandpass filter
2026-03-01 Revision D: improvements and corrections
    * Added a pulldown resistor in the VHF switch line.
    * Refactored the CPW between the relays, hoping this tackle the high
    VSWR found in 70 cm band.
    * Removed exposed pads that existed in previous version, that might eff up
    and cause capacitive coupling
    * Updated RF testing section
    * Updated BOM
    * Resolves: #26
    * Resolves: #28
    [SS.brd, SS.csv, SS.sch]
2026-03-19 Removed two RF switches
    Removed two unneeded RF switches at the front-end: extra cost,
    complexity and insertion loss - unnecessarily, as the RF stage
    is handsomely isolated - and powered off during high power operations.
    [SS.brd, SS.csv, SS.sch]
2026-05-06 Launching: Rev. E
    * Complete rewrite of VHF BPF to a proper 3-pole ¤
    * Improved UHF filter performance significantly¤
    * Implemented a proper 50 ohm GCPW setup ¤
    * Re-added soldermask into the signal path ¤
    * Added a two-pole and three-pole test pad at the back of the board
    * Fixed u.FL connectors lacking connection to ground in one side
    * Added keep-out zones for RF inductors ¤
    * Replaced the 3V regulator with one that can withstand the Vin ¤
    * Separated the top ground plane on north/south: The north (RF) section
    doesn't have any thermal relief in GND pads. The south (ancillary)
    section contains thermal relief GND pads. ¤
    * Fixed wrong limiters & pulldowns across the board ¤
    All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
    [SS.brd, SS.sch]
2026-05-18 BOM: Updated parts to sync with Rev. E
    [SS.csv]
2026-05-18 BOM reordering
    [SS.csv]
2026-05-29 Rev. E bug fixes
    * Added new VHF filter test figures
    * Fixed a gross error where a via shorted the VHF BPF final coupling stage
    * Removed ground pad on inductors at the detachable VHF BPF.
    * Improved the radio signal trace at the first RF relay input.
    * Updated component values for the 3-pole VHF filter (*in vivo* performed differently than the *in vitro*)
    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
    [SS.brd, SS.csv, SS.sch]
2026-06-06 UHF filter improvements and testing figures.
    [SS.brd, SS.csv, SS.sch]
2026-06-06 Updated board specs
2026-06-11 Added another series capacitor in 2 pole test filter
    The two-pole filter, used to tune/test/evaluate UHF filters sometimes
    requires a very small capacitance value. Adding a second serial coupling
    cap in case of need to put them in series to reduce capacitance and yield
    a lower value. Otherwise, jumper it with a 0 ohm chip resistor/jumper.
    [SS.brd, SS.sch]
2026-06-14 Board: Ran a DRC and wiped out some shenanigans
    [SS.brd]
2026-09-18 Releasing: Revision F
    * Improved UHF BPF.
    * Changed "Bypass" and "VHF/UHF" input selectors from 3V to 5V via
    resisitive divisors.
    * Added u.FL calibration pads.
    * Updated documentation, BOM, images, tests
    * Resolves #30
    [SS.brd, SS.csv, SS.sch]
2026-09-19 Improvements on test/assembly instructions
    Updated testing instructions for VHF and LNA performance, clarified steps for soldering and measuring outputs, and improved readability of operational logic.
